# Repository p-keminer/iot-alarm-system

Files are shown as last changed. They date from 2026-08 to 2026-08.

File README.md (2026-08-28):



<div align="center">




</div>

---

<div align="center">
  <a href="#">
   
  </a>
  &nbsp;&nbsp;&nbsp;&nbsp;&nbsp;&nbsp;
  <a href="#">
    
  </a>
  &nbsp;&nbsp;&nbsp;&nbsp;&nbsp;&nbsp;
 <a href="#">
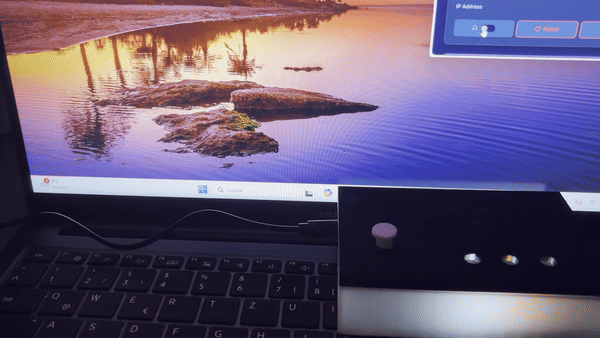
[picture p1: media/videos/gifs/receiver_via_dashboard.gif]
    
  </a>
</div>

---

# IoT-Alarmanlage

Die IoT-Alarmanlage basiert auf einem `Elegoo Uno R3`, zwei `ESP8266` und einem `Raspberry Pi Zero 2 W`. RFID und zwei Reed-Sensoren steuern die lokale Alarm-FSM. Ein Funkpfad uebertraegt Alarmzustaende an den Empfaenger; das Dashboard zeigt Telemetrie, Logs und Aufnahmen und sendet freigegebene Befehle.

Dieses Projekt entstand in meinem ersten Studiensemester und war mein erstes Lernprojekt.

```text
RFID + 2x Reed -> Uno-FSM -> UART -> ESP-Sender -> HMAC-UDP -> ESP-Empfaenger
                         |
                         +-> USB-Serial <-> Alarm-Monitor <-> lokale IPC <-> Dashboard

ESP-Sender + ESP-Empfaenger <-> HTTP/JSON im isolierten IoT-WLAN <-> Raspberry Pi / PHP-API
```

## Aktueller Stand

| Ziel | Aktiver Sketch |
|---|---|
| Uno R3 | `firmware/elegoo_uno_r3/sketchR3/alarm_system/alarm_system.ino` |
| ESP-Sender | `firmware/esp8266/sender/sender.ino` |
| ESP-Empfaenger | `firmware/esp8266/receiver/receiver.ino` |

- Der Uno akzeptiert ohne private `uid_whitelist.local.h` keine Karte. Scharf-/Alarmzustand liegt CRC-geschuetzt in zwei EEPROM-Slots; ein offener Reed-Kreis loest scharf Alarm aus.
- UDP nutzt HMAC-SHA256, strikt monotone persistente Sequenzen und signierte ACKs. HTTP-Zustellungen nutzen getrennte Geraete-Token/-HMACs und ein durables `ALARMv2`-Apply-Journal.
- `nginx`/`PHP-FPM` bedienen den Browser per HTTPS und die ESPs ueber einen auf das IoT-WLAN beschraenkten HTTP-Endpunkt. Der Dienst `iot-alarm-monitor` besitzt exklusiv Serial, Recorder und deren Loeschpfade.
- Der Prototyp besitzt keine formale Produkt-, Safety- oder Security-Freigabe.

## Repository

| Pfad | Inhalt |
|---|---|
| `firmware/` | drei aktive Arduino-Ziele |
| `web/` | Dashboard, API, Monitor und Deploy-Vorlagen |
| `hardware/` | KiCad-, Gerber- und Aufbauquellen |
| `mechanics/` | STL-Dateien und Vorschauen |
| `media/` | Projektfotos und fuenf Demo-GIFs |
| `docs/`, `tests/` | kanonische Dokumentation und Nachweise |

## Einstieg

[Build](docs/BUILD.md#deutsch) · [Hardware](docs/HARDWARE.md#deutsch) · [Web-Dashboard](web/README.md#deutsch) · [Tests](docs/TESTING.md#deutsch) · [Safety](SAFETY.md#deutsch) · [Security](SECURITY.md#deutsch)

## Sicherheitsgrenze

Das System ist ein nicht zertifizierter Lernprototyp. Ausfaelle von Strom, Funk, Speicher, Kamera oder Hardware koennen seine Funktion beeintraechtigen.

## Lokale Konfiguration

RFID-UIDs, WLAN-Daten, Token, HMAC-Secrets, Passwoerter, PINs und Laufzeitdaten bleiben lokal. Vorlagen enden auf `.example`; private Werte liegen in ignorierten `*.local.*`-Dateien oder im geschuetzten `web/data/`.

## Lizenz

Projekt-eigene Inhalte stehen unter der [MIT-Lizenz](LICENSE.md); Drittmaterial behaelt seine jeweiligen Rechte.

<div align="center">



</div>

---

# IoT Alarm System

The IoT alarm system uses an `Elegoo Uno R3`, two `ESP8266` nodes, and a `Raspberry Pi Zero 2 W`. RFID and two reed sensors drive the local alarm FSM. A radio link sends alarm states to the receiver; the dashboard displays telemetry, logs, and recordings and sends approved commands.

This project began during the first semester of my degree and was my first learning project.

```text
RFID + 2x reed -> Uno FSM -> UART -> ESP sender -> HMAC UDP -> ESP receiver
                           |
                           +-> USB serial <-> alarm monitor <-> local IPC <-> dashboard

ESP sender + ESP receiver <-> HTTP/JSON on the isolated IoT WiFi <-> Raspberry Pi / PHP API
```

## Current Status

| Target | Active sketch |
|---|---|
| Uno R3 | `firmware/elegoo_uno_r3/sketchR3/alarm_system/alarm_system.ino` |
| ESP sender | `firmware/esp8266/sender/sender.ino` |
| ESP receiver | `firmware/esp8266/receiver/receiver.ino` |

- Without private `uid_whitelist.local.h`, the Uno accepts no card. Armed/alarm state is CRC-protected across two EEPROM slots; either open reed circuit triggers an armed system.
- UDP uses HMAC-SHA256, strict monotonic persistent sequences, and signed ACKs. HTTP delivery uses separate device tokens/HMACs and a durable `ALARMv2` apply journal.
- `nginx`/`PHP-FPM` serve the browser over HTTPS and the ESPs through an HTTP endpoint restricted to the IoT WiFi. The `iot-alarm-monitor` service exclusively owns serial, the recorder, and their deletion paths.
- The prototype has no formal product, safety, or security approval.

## Repository

| Path | Contents |
|---|---|
| `firmware/` | three active Arduino targets |
| `web/` | dashboard, API, monitor, and deployment templates |
| `hardware/` | KiCad, Gerber, and assembly sources |
| `mechanics/` | STL files and previews |
| `media/` | project photos and five demo GIFs |
| `docs/`, `tests/` | canonical documentation and evidence |

## Getting Started

[Build](docs/BUILD.md#english) · [Hardware](docs/HARDWARE.md#english) · [Web dashboard](web/README.md#english) · [Tests](docs/TESTING.md#english) · [Safety](SAFETY.md#english) · [Security](SECURITY.md#english)

## Security Boundary

The system is an uncertified learning prototype. Power, radio, storage, camera, or hardware failures may impair its operation.

## Local Configuration

RFID UIDs, WiFi credentials, tokens, HMAC secrets, passwords, PINs, and runtime data remain local. Templates end in `.example`; private values live in ignored `*.local.*` files or protected `web/data/`.

## License

Project-owned content uses the [MIT License](LICENSE.md); third-party material retains its respective rights.

<div align="center">



</div>

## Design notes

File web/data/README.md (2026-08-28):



<div align="center">




</div>

---

# Laufzeitdaten

Dieses Verzeichnis enthaelt den lokalen Zustand einer Installation. Ausser dieser README wird nichts daraus eingecheckt.

| Pfad | Inhalt |
|---|---|
| `settings.json` | Hashes, getrennte Geraete-Token/-HMACs, UDP-Secret und Einstellungen |
| `settings.bootstrap.lock` | Prozess-Lock fuer Bootstrap und Secret-Rotation |
| `.bootstrap-credentials` | Bootstrap-Fallback, nur wenn kein externer Pfad gesetzt ist |
| `status.json` | letzter ESP-/Kamerastatus, nicht der Uno-Zustand |
| `commands.json`, `update_*.json` | offene Node-Kommandos und -Konfigurationen |
| `delivery_state.json`, `delivery_queue.lock` | monotone Zaehler und Zustell-Lock |
| `alarm_monitor.json` | alleinige Dashboard-Quelle fuer Uno, Serial und Aufnahme |
| `telemetry.csv` | Telemetrie-Zeitreihe |
| `log.txt`, `log.txt.1`, `log.txt.2` | groessenbegrenzt rotierter Alarm-Monitor-Log |
| `api.log`, `user_logs.json` | begrenzter API-/Geraete-Log und Administrator-Auditlog |
| `login_attempts.json` | Login-Brute-Force-Tracking |
| `alarm_pin_attempts.json` | getrenntes Alarm-PIN-Lockout-Ledger |
| `ratelimit/` | API-Ratenzaehler pro Quell-IP |
| `recordings/` | lokale Kameraaufnahmen |

Im kanonischen Deployment zeigt `IOT_ALARM_BOOTSTRAP_FILE` vor dem ersten Aufruf auf eine `0600`-Datei ausserhalb des Webroots. Ohne diesen Wert verwendet die Anwendung `.bootstrap-credentials` in diesem von nginx gesperrten Verzeichnis. Nach Passwort-/PIN-Wechsel und ESP-Provisionierung sicher loeschen.

Das Datenverzeichnis ist setgid `2770`, `recordings/` ist `0750`, regulaere Runtime-Dateien sind `0640` und der Bootstrap-Fallback ist `0600`. Der Daemon besitzt den Serial-/Recorderpfad; sein Socket liegt separat unter `/run/iot-alarm-monitor/control.sock` als `0660` fuer die Gruppe `www-data`. Vollstaendige Einrichtung: [Build](../../docs/BUILD.md#de-web-deployment).

Die Daten koennen Secrets, IP-Adressen, Zeitstempel und Aufnahmen enthalten. Backups gleich streng schuetzen, nicht oeffentlich weitergeben und nach der Aufbewahrungsfrist loeschen. Siehe [Security](../../SECURITY.md#deutsch).

<div align="center">



</div>

---

# Runtime Data

This directory contains the local state of an installation. Nothing except this README is committed.

| Path | Contents |
|---|---|
| `settings.json` | hashes, separate device tokens/HMACs, UDP secret, and settings |
| `settings.bootstrap.lock` | process lock for bootstrap and secret rotation |
| `.bootstrap-credentials` | bootstrap fallback only when no external path is set |
| `status.json` | latest ESP/camera status, not Uno state |
| `commands.json`, `update_*.json` | pending node commands and configurations |
| `delivery_state.json`, `delivery_queue.lock` | monotonic counters and delivery lock |
| `alarm_monitor.json` | sole dashboard source for Uno, serial, and recording state |
| `telemetry.csv` | telemetry time series |
| `log.txt`, `log.txt.1`, `log.txt.2` | size-bounded rotating alarm-monitor log |
| `api.log`, `user_logs.json` | bounded API/device log and administrator audit log |
| `login_attempts.json` | login brute-force tracking |
| `alarm_pin_attempts.json` | separate alarm-PIN lockout ledger |
| `ratelimit/` | API rate counters by source IP |
| `recordings/` | local camera recordings |

In the canonical deployment, `IOT_ALARM_BOOTSTRAP_FILE` points to a `0600` file outside the web root before the first request. Without that value, the application uses `.bootstrap-credentials` in this nginx-blocked directory. Delete it securely after password/PIN changes and ESP provisioning.

The data directory is setgid `2770`, `recordings/` is `0750`, regular runtime files are `0640`, and the bootstrap fallback is `0600`. The daemon owns serial and recording resources; its separate socket is `/run/iot-alarm-monitor/control.sock`, mode `0660`, for group `www-data`. See [Build](../../docs/BUILD.md#en-web-deployment) for complete setup.

The data may contain secrets, IP addresses, timestamps, and recordings. Protect backups equally, do not share them publicly, and delete them after their retention period. See [Security](../../SECURITY.md#english).

<div align="center">



</div>

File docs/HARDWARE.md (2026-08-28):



<div align="center">




</div>

---

# Hardware

Die Pinbelegung ist aus den drei aktiven Sketchen abgeleitet. Schaltbilder und KiCad-Dateien bleiben die Referenz fuer den realen Aufbau; vor dem Einschalten immer gegen die vorhandene Platine pruefen.

## Komponenten

| Anzahl | Komponente | Aufgabe |
|---:|---|---|
| 1 | Elegoo Uno R3 / ATmega328P | lokale Alarm-FSM, RFID und Reed-Sensoren |
| 2 | NodeMCU V2 / ESP8266 | Funk-Sender und entfernter Empfaenger |
| 1 | Raspberry Pi Zero 2 W | Dashboard, API, Serial-Monitor, optionale Kamera |
| 1 + 2 | MFRC522 + KY-021 / Reed-Modul | RFID-Zugang und Tuer-/Fensterkontakte |
| 3 + 7 | aktive Summer + LEDs | akustischer Alarm und Statusanzeigen |
| 1 | Raspberry-Pi-Kameramodul | optionale Alarmaufnahme |

Erforderlich sind ausserdem passende LED-Vorwiderstaende, ein Pegelwandler oder berechneter Spannungsteiler fuer Uno TX, Taster, Steckverbinder und eine stabile Versorgung.

## Pinbelegung

### Uno R3

| Pin | Funktion | Hinweis |
|---|---|---|
| `D0/RX` | Befehle ueber USB-Serial | gemeinsame Hardware-UART |
| `D1/TX` | Events an ESP-Sender und USB-Serial | `5 V`; zum ESP pegeln |
| `D2`, `D3` | Reed-Sensor 1 und 2 | `INPUT_PULLUP`; `HIGH` = offen |
| `D5` | lokaler Summer | Ausgang |
| `D6`, `D7`, `D8` | Alarm-/Scharf-LED, Sensor-LED 1 und 2 | Ausgang |
| `D9` | MFRC522 `RST` | `3.3 V`-Peripherie |
| `D10` | MFRC522 `SS/SDA` | SPI Chip Select |
| `D11`, `D12`, `D13` | MFRC522 `MOSI`, `MISO`, `SCK` | `D13` teilt die Board-LED |

Bereits ein offener Reed-Kreis loest im scharfen Zustand aus. Scharf- und Alarmzustand liegen mit Sequenz, CRC und Commit-Markierung in zwei EEPROM-Slots; ein beschaedigter nichtleerer Stand startet fail-secure im Alarm. Ohne lokale UID-Datei akzeptiert der Uno keine RFID-Karte.

### ESP8266-Sender

| NodeMCU-Pin | GPIO | Funktion |
|---|---:|---|
| `RX` | `GPIO3` | `ALARM_ON`/`ALARM_OFF` vom Uno, `9600` Baud |
| `D3` | `GPIO0` | Factory-Reset-Taster, `INPUT_PULLUP` |
| `D5` | `GPIO14` | WLAN-LED |
| `LED_BUILTIN` | `GPIO2` | Alarm-/Sende-LED, aktiv-low |

Der Factory Reset wird erst nach mehr als zehn Sekunden Tastendruck beim Loslassen ausgeloest. `GPIO0` und `GPIO2` beeinflussen den Bootmodus; externe Schaltungen muessen die erforderlichen Einschaltpegel erhalten.

### ESP8266-Empfaenger

| NodeMCU-Pin | GPIO | Funktion |
|---|---:|---|
| `D1`, `D2` | `GPIO5`, `GPIO4` | rote und gelbe Alarm-LED |
| `D3` | `GPIO0` | WLAN-LED |
| `D5`, `D6` | `GPIO14`, `GPIO12` | Summer 1 und 2 |
| `D7` | `GPIO13` | Toggle-/Factory-Reset-Taster, `INPUT_PULLUP` |

Ein Druck unter einer Sekunde schaltet den entfernten Alarm um. Mehr als zehn Sekunden loesen beim Loslassen den Factory Reset aus; dazwischen erfolgt keine Aktion.

## Versorgung und Pegel

- Alle verbundenen Baugruppen brauchen eine gemeinsame Masse.
- ESP8266-GPIOs und MFRC522 arbeiten mit `3.3 V`; Uno TX zum ESP pegeln.
- Eine stabile Versorgung und Abblockung muessen WLAN-Stromspitzen tragen.
- Fuer einen per USB versorgten Uno ist der Sender mit externer ESP-Versorgung die empfohlene Variante.
- Stromhungrige Summer oder mehrere LEDs bei Bedarf ueber Treiber schalten.
- Es gibt keine galvanische Trennung. Vor Umverdrahtung Strom und USB trennen.

## Leiterplatten und Mechanik

| Pfad | Inhalt | Fertigungsdaten |
|---|---|---|
| `hardware/pcb/receiver/` | Empfaenger-KiCad-Projekt und Renderings | `receiver_gerber.zip` |
| `hardware/pcb/sender/` | Sender-Basisprojekt und Renderings | `sender_r3_gerber.zip` |
| `hardware/pcb/sender/sender_r3_external.*` | Sender mit externer ESP-Versorgung | `sender_r3_external_gerber/` |

Die ZIPs sind fuer Basis-Sender und Empfaenger kanonisch; fuer die externe Variante ist der lose Gerber-Satz die einzige Fertigungsquelle. Vor Bestellung Lagen, Bohrungen, Kontur, Leiterbahnbreiten, Polaritaeten und Abmessungen im Gerber-Viewer pruefen. Die Dateien sind keine Produktionsfreigabe.

| STL-Verzeichnis | Modell |
|---|---|
| `mechanics/prints_3d/sender/` | Sendergehaeuse R3 |
| `mechanics/prints_3d/receiver/` | Empfaengergehaeuse |
| `mechanics/prints_3d/reed_sensor/` | Reed-Sensorgehaeuse |
| `mechanics/prints_3d/rfid_sensor/` | RFID-Lesergehaeuse |

Jeder Ordner enthaelt eine STL-Datei und eine Vorschau. Toleranzen, Schraubpunkte und Ausschnitte vor dem Druck an der realen Hardware pruefen.

## Aufbau

1. Versorgung und Pegel ohne Controller messen; dann Uno, RFID und beide Reed-Kreise einzeln testen.
2. Sender und Empfaenger getrennt flashen und lokal provisionieren.
3. UART nur mit gemeinsamer Masse und korrektem Pegel verbinden.
4. Funkpfad zuerst ohne laute Aktoren pruefen; Pi, API und Kamera zuletzt anbinden.

Aufbaufotos liegen unter `media/photos/`, Schalt- und Lochrasterzeichnungen unter `hardware/schematics/`.

<div align="center">



</div>

---

# Hardware

The pin map is derived from the three active sketches. Schematics and KiCad files remain the reference for the physical build; always compare them with the actual board before applying power.

## Components

| Qty | Component | Purpose |
|---:|---|---|
| 1 | Elegoo Uno R3 / ATmega328P | local alarm FSM, RFID, and reed sensors |
| 2 | NodeMCU V2 / ESP8266 | radio sender and remote receiver |
| 1 | Raspberry Pi Zero 2 W | dashboard, API, serial monitor, optional camera |
| 1 + 2 | MFRC522 + KY-021 / reed module | RFID access and door/window contacts |
| 3 + 7 | active buzzers + LEDs | audible alarm and status indicators |
| 1 | Raspberry Pi camera module | optional alarm recording |

The build also needs suitable LED resistors, a level shifter or calculated divider for Uno TX, buttons, connectors, and a stable power supply.

## Pin Map

### Uno R3

| Pin | Function | Note |
|---|---|---|
| `D0/RX` | commands over USB serial | shared hardware UART |
| `D1/TX` | events to ESP sender and USB serial | `5 V`; shift for ESP |
| `D2`, `D3` | reed sensors 1 and 2 | `INPUT_PULLUP`; `HIGH` = open |
| `D5` | local buzzer | output |
| `D6`, `D7`, `D8` | alarm/armed LED, sensor LEDs 1 and 2 | output |
| `D9` | MFRC522 `RST` | `3.3 V` peripheral |
| `D10` | MFRC522 `SS/SDA` | SPI chip select |
| `D11`, `D12`, `D13` | MFRC522 `MOSI`, `MISO`, `SCK` | `D13` shares the board LED |

Either open reed circuit triggers an armed system. Armed and alarm state use sequence, CRC, and commit markers across two EEPROM slots; corrupt non-empty state boots fail-secure into alarm. Without a local UID file, the Uno accepts no RFID card.

### ESP8266 Sender

| NodeMCU pin | GPIO | Function |
|---|---:|---|
| `RX` | `GPIO3` | `ALARM_ON`/`ALARM_OFF` from Uno at `9600` baud |
| `D3` | `GPIO0` | factory-reset button, `INPUT_PULLUP` |
| `D5` | `GPIO14` | WiFi LED |
| `LED_BUILTIN` | `GPIO2` | alarm/transmit LED, active-low |

Factory reset occurs on release after holding the button for more than ten seconds. `GPIO0` and `GPIO2` affect boot mode; external circuitry must preserve the required levels during power-up.

### ESP8266 Receiver

| NodeMCU pin | GPIO | Function |
|---|---:|---|
| `D1`, `D2` | `GPIO5`, `GPIO4` | red and yellow alarm LEDs |
| `D3` | `GPIO0` | WiFi LED |
| `D5`, `D6` | `GPIO14`, `GPIO12` | buzzers 1 and 2 |
| `D7` | `GPIO13` | toggle/factory-reset button, `INPUT_PULLUP` |

A press below one second toggles the remote alarm. More than ten seconds triggers factory reset on release; the interval between them has no action.

## Power and Logic Levels

- Every connected board needs a common ground.
- ESP8266 GPIO and the MFRC522 use `3.3 V`; level-shift Uno TX to the ESP.
- A stable, decoupled supply must support WiFi current peaks.
- For a USB-powered Uno, the sender with an external ESP supply is recommended.
- Drive high-current buzzers or multiple LEDs through suitable drivers.
- There is no galvanic isolation. Disconnect power and USB before rewiring.

## PCBs and Mechanics

| Path | Contents | Manufacturing data |
|---|---|---|
| `hardware/pcb/receiver/` | receiver KiCad project and renderings | `receiver_gerber.zip` |
| `hardware/pcb/sender/` | base sender project and renderings | `sender_r3_gerber.zip` |
| `hardware/pcb/sender/sender_r3_external.*` | sender with external ESP supply | `sender_r3_external_gerber/` |

The ZIPs are canonical for the base sender and receiver; the loose Gerbers are the only manufacturing source for the external variant. Before ordering, verify layers, drills, outline, trace widths, polarities, and dimensions in a Gerber viewer. These files are not a production release.

| STL directory | Model |
|---|---|
| `mechanics/prints_3d/sender/` | R3 sender enclosure |
| `mechanics/prints_3d/receiver/` | receiver enclosure |
| `mechanics/prints_3d/reed_sensor/` | reed-sensor enclosure |
| `mechanics/prints_3d/rfid_sensor/` | RFID-reader enclosure |

Each directory contains one STL and one preview. Check tolerances, mounting points, and cut-outs against the real hardware before printing.

## Assembly

1. Measure power and logic levels without controllers; then test the Uno, RFID reader, and both reed circuits.
2. Flash and locally provision sender and receiver separately.
3. Connect UART only with common ground and the correct logic level.
4. Test the radio path without loud actuators; integrate Pi, API, and camera last.

Assembly photos are under `media/photos/`; circuit and perfboard drawings are under `hardware/schematics/`.

<div align="center">



</div>

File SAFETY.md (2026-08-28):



<div align="center">




</div>

---

# Safety

Dieses Repository beschreibt einen nicht zertifizierten Lern- und Demonstrationsprototyp.

## Grenzen

- Das System ist keine zertifizierte Alarmanlage.
- Strom-, WLAN-, Software-, Sensor-, Speicher- und Verdrahtungsfehler koennen LEDs, Summer, Webstatus und Kamera ausfallen lassen.
- Ein offener Reed-Kreis loest scharf Alarm aus. Das behandelt Kabelbruch konservativ, ist aber keine zertifizierte Sabotageerkennung.
- Der Uno stellt Scharf-/Alarmzustand aus EEPROM wieder her; ein Neustart schaltet nicht unscharf.
- Bei unlesbarem Sicherheitszustand aktiviert der Empfaenger fail-secure seine Aktoren. Der lokale Uno-Pfad bleibt auch bei Ausfall von Funk oder Dashboard massgeblich.

## Kamera und Datenschutz

Nur eigene oder ausdruecklich freigegebene Bereiche aufnehmen. Aufnahmen und Logs koennen Personen, Zeitstempel, IP-Adressen und Anwesenheitsmuster enthalten; lokale Gesetze, Informationspflichten, Zugriffsschutz, verschluesselte Backups und Aufbewahrungsfristen beachten.

Netzwerk- und Zugriffsgrenzen: [Security](SECURITY.md#deutsch).

<div align="center">



</div>

---

# Safety

This repository documents an uncertified learning and demonstration prototype.

## Limitations

- The system is not a certified alarm system.
- Power, WiFi, software, sensor, storage, and wiring faults can disable LEDs, buzzers, web status, or the camera.
- Either open reed circuit triggers an armed system. This treats a broken wire conservatively but is not certified tamper detection.
- The Uno restores armed/alarm state from EEPROM; a restart does not disarm it.
- Unreadable security state makes the receiver fail-secure drive its actuators. The local Uno path remains authoritative if radio or dashboard access fails.

## Camera and Privacy

Record only your own areas or areas with explicit permission. Recordings and logs may contain people, timestamps, IP addresses, and presence patterns; observe local law, notification duties, access control, encrypted backups, and retention periods.

Network and access boundaries: [Security](SECURITY.md#english).

<div align="center">



</div>

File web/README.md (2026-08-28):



<div align="center">




</div>

---

# Web-Dashboard

Die leichtgewichtige PHP-Anwendung fuer den Raspberry Pi Zero 2 W verwendet JSON-/CSV-Dateien statt einer Datenbank. Sie verbindet ESP-Telemetrie und -Kommandos, den Uno ueber einen dedizierten Serial-Dienst sowie optionale Kamera-Streams und Alarmaufnahmen.

## Ansichten

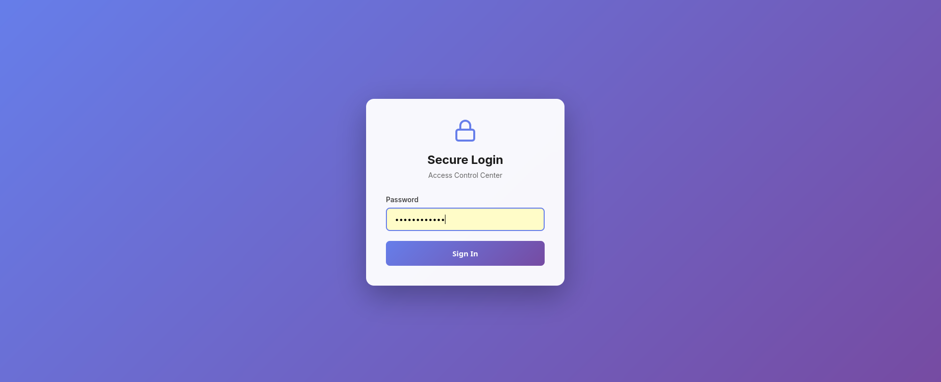
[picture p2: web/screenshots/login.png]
Login

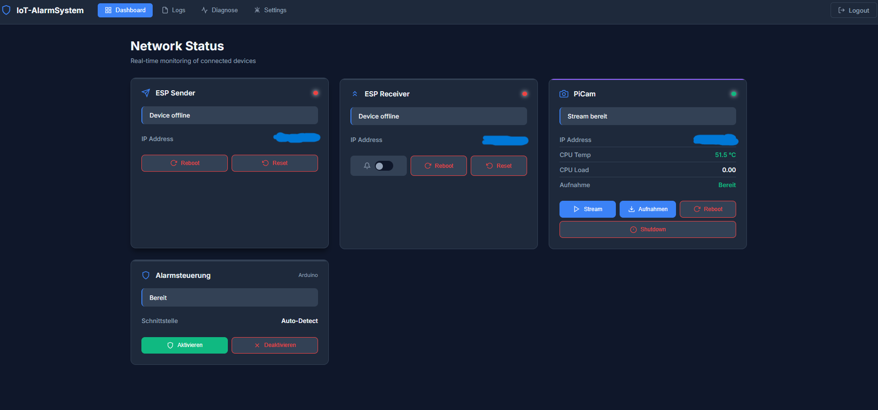
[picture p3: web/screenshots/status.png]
Status

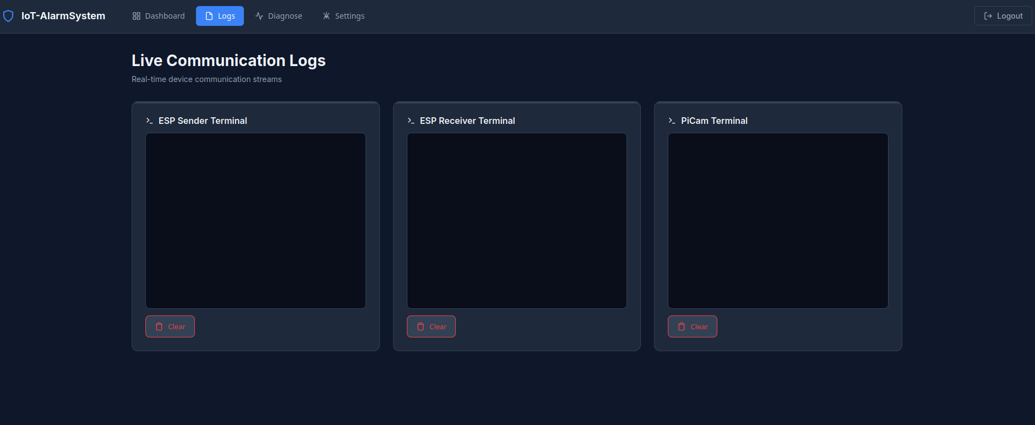
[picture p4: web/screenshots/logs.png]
Logs

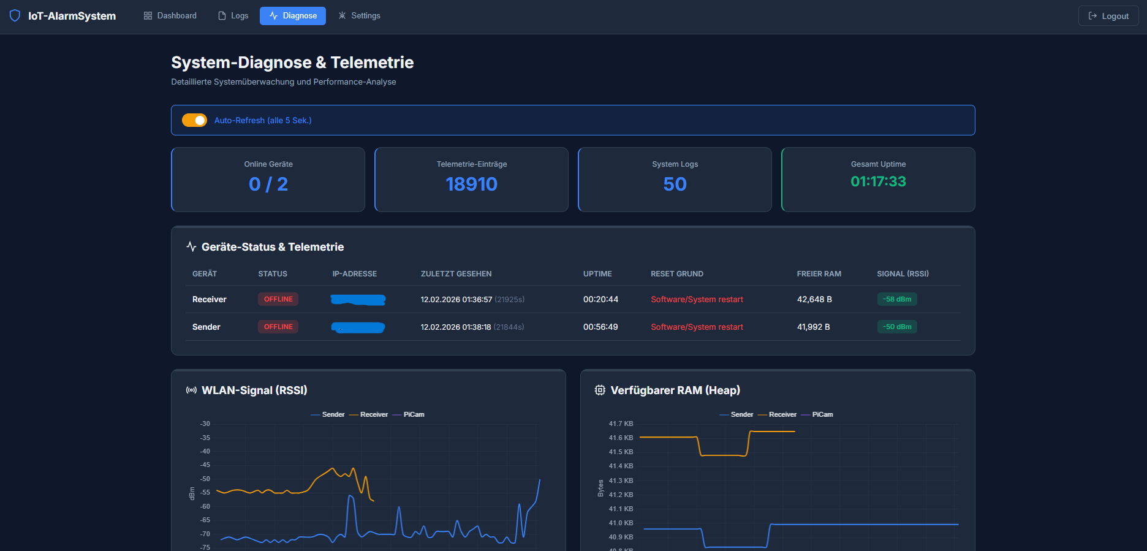
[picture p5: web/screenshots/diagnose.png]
Diagnose

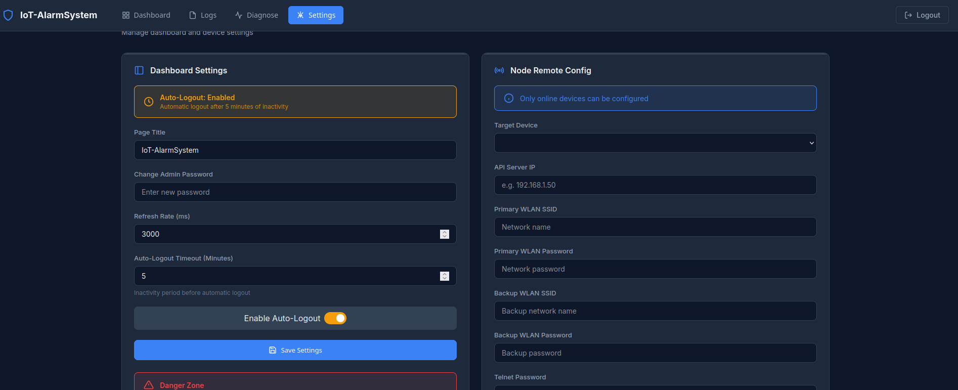
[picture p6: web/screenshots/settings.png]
Einstellungen

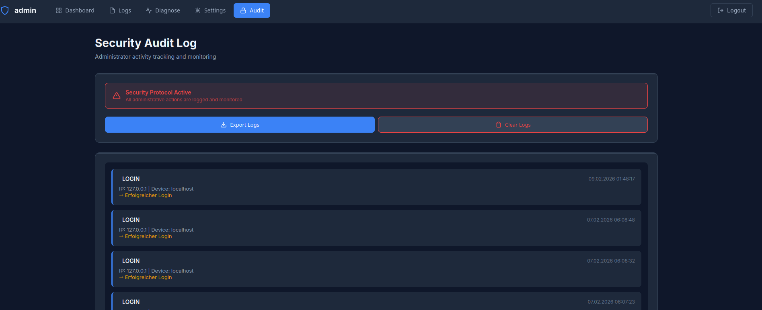
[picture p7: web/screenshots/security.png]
Audit


## Architektur

| Pfad | Aufgabe |
|---|---|
| `index.php`, `login.php` | geschuetzte Oberflaeche und Login |
| `api.php` | Dashboard-Aktionen und ESP-Endpunkt |
| `stream.php` | authentifizierte Kameraansicht |
| `includes/` | Konfiguration, Authentifizierung und Datenzugriff |
| `views/`, `css/`, `js/` | statische Oberflaeche |
| `alarm_monitor.py` | alleiniger Serial-, Recorder- und Loeschprozess |
| `alarm_monitor.service` | gehaertete systemd-Unit |
| `deploy/` | nginx-, Fail2ban- und systemd-Vorlagen |
| `data/` | ignorierter lokaler Laufzeitzustand |

Browserzugriff erreicht nginx ausschliesslich ueber HTTPS; Port 80 leitet auf den festen HTTPS-Namen um. Ein separater HTTP-Listener bindet die IP-Adresse des Pi im IoT-WLAN, erlaubt nur dessen isoliertes Subnetz und stellt dort ausschliesslich `api.php` bereit. Interne Verzeichnisse und Dateitypen werden nicht statisch ausgeliefert.

PHP oeffnet weder Serial noch ffmpeg. Freigegebene Aktionen gehen ueber den
lokalen Socket `/run/iot-alarm-monitor/control.sock` an den Dienst; nur dieser
Prozess besitzt `dialout`, Recorder und Aufnahme-Loeschpfad.

## Funktionen

- Live-Status, RSSI, Heap, Uptime und Resetgrund beider ESPs
- Kommunikations-, System- und Auditlogs sowie Telemetrie-CSV
- Auditansicht/-export mit fuenf Minuten gueltiger serverseitiger PIN-Freigabe
- PIN-Schutz fuer Alarm, Reboot, Datenreset und Aufnahmeaktionen
- getrennte Node-Kommandos und -Konfigurationen mit Geraete-ACK
- Admin-Passwort, Alarm-PIN, Session-Timeout und Aktualisierungsintervall
- optionale MJPEG-Ansicht sowie automatische und manuelle Aufnahmen

Google Fonts, `unpkg.com` und `jsDelivr` bleiben externe Browserabhaengigkeiten.
Ohne Internet funktionieren die Serverpfade weiter; Icons, Schrift oder Charts
koennen fehlen. Die Grenze ist in [Security](../SECURITY.md#deutsch) bewertet.

## Ersteinrichtung

Eine neue Installation erzeugt Admin-Passwort, Alarm-PIN, getrennte API-/Delivery-Secrets fuer Sender, Empfaenger und Kamera sowie ein eigenes UDP-Secret. Es gibt keine bekannten Standardzugangsdaten.

1. Deployment nach [Build](../docs/BUILD.md#de-web-deployment) installieren.
2. Dashboard ueber HTTPS aufrufen und Bootstrap-Datei lokal lesen.
3. Admin-Passwort und Alarm-PIN ersetzen.
4. Jeden ESP mit seinem eigenen API-/Delivery-Paar und dem gemeinsamen
   UDP-Secret provisionieren.
5. Bootstrap-Datei sicher loeschen.

## Alarm-Monitor und Betrieb

Der Dienst akzeptiert Serial nur nach einem gueltigen `STATUS`-Handshake,
gleicht den Zustand periodisch ab und bestaetigt Scharf-/Unscharf-Befehle erst
nach passendem Snapshot. Bei Verbindungsverlust bleibt ein Alarm konservativ
erhalten. Aufnahmen besitzen Zeit-, Groessen- und Speichergrenzen, begrenzte
Start-Retries und Schutz vor dem Loeschen der aktiven Datei. `log.txt` rotiert;
PHP schreibt getrennt nach `api.log`. Die aktuellen Grenzwerte stehen in der
[Dienstvorlage](deploy/systemd/iot-alarm-monitor.env.example).

```bash
sudo nginx -t
sudo systemctl status nginx php8.4-fpm iot-alarm-monitor.service
sudo journalctl -u iot-alarm-monitor.service -f
sudo ls -l /run/iot-alarm-monitor/control.sock
sudo fail2ban-client status iot-login
```

Runtime-Dateien nie committen oder oeffentlich weitergeben; ihr Manifest
steht in [data/README.md](data/README.md#deutsch). Der ESP-HTTP-Endpunkt darf
nicht aus WAN, Gast-, Campus- oder anderen unkontrollierten Netzen erreichbar
sein.

<div align="center">



</div>

---

# Web Dashboard

This lightweight PHP application for the Raspberry Pi Zero 2 W uses JSON/CSV files instead of a database. It combines ESP telemetry and commands, Uno control through a dedicated serial service, and optional camera streams and alarm recordings.

## Views

Login
Status
Logs
Diagnostics
Settings
Audit

## Architecture

| Path | Purpose |
|---|---|
| `index.php`, `login.php` | protected interface and login |
| `api.php` | dashboard actions and ESP endpoint |
| `stream.php` | authenticated camera view |
| `includes/` | configuration, authentication, and data access |
| `views/`, `css/`, `js/` | static interface |
| `alarm_monitor.py` | sole serial, recorder, and deletion process |
| `alarm_monitor.service` | hardened systemd unit |
| `deploy/` | nginx, Fail2ban, and systemd templates |
| `data/` | ignored local runtime state |

Browser access reaches nginx only over HTTPS; port 80 redirects to the fixed HTTPS name. A separate HTTP listener binds the Pi address on the IoT WiFi, permits only that isolated subnet, and exposes only `api.php`. Internal directories and file types are never served statically.

PHP opens neither serial nor ffmpeg. Approved actions reach the service over
the local `/run/iot-alarm-monitor/control.sock` socket; only that process owns
`dialout`, the recorder, and recording deletion.

## Features

- live status, RSSI, heap, uptime, and reset reason for both ESPs
- communication, system, and audit logs plus telemetry CSV
- audit view/export with a five-minute server-side PIN grant
- PIN protection for alarm, reboot, data reset, and recording actions
- separate node commands and configurations with device ACKs
- admin password, alarm PIN, session timeout, and refresh interval
- optional MJPEG view plus automatic and manual recordings

Google Fonts, `unpkg.com`, and `jsDelivr` remain external browser dependencies.
Server paths keep working offline, but icons, fonts, or charts may be missing.
This boundary is assessed in [Security](../SECURITY.md#english).

## First-Time Setup

A new installation creates an admin password, alarm PIN, separate API/delivery
secrets for sender, receiver, and camera, plus a separate UDP secret. There are
no known default credentials.

1. Install the deployment from [Build](../docs/BUILD.md#en-web-deployment).
2. Open the dashboard over HTTPS and read the bootstrap file locally.
3. Replace the admin password and alarm PIN.
4. Provision each ESP with its own API/delivery pair and the shared UDP secret.
5. Securely delete the bootstrap file.

## Alarm Monitor and Operation

The service accepts serial only after a valid `STATUS` handshake, periodically
reconciles state, and confirms arm/disarm only after a matching snapshot. It
conservatively retains an alarm on connection loss. Recordings have time,
size, and free-space limits, bounded start retries, and active-file deletion
protection. `log.txt` rotates; PHP writes separately to `api.log`. Current
limits live in the [service template](deploy/systemd/iot-alarm-monitor.env.example).

```bash
sudo nginx -t
sudo systemctl status nginx php8.4-fpm iot-alarm-monitor.service
sudo journalctl -u iot-alarm-monitor.service -f
sudo ls -l /run/iot-alarm-monitor/control.sock
sudo fail2ban-client status iot-login
```

Never commit or publicly share runtime files; see their manifest
in [data/README.md](data/README.md#english). The ESP HTTP endpoint must not be
reachable from WAN, guest, campus, or other untrusted networks.

<div align="center">



</div>

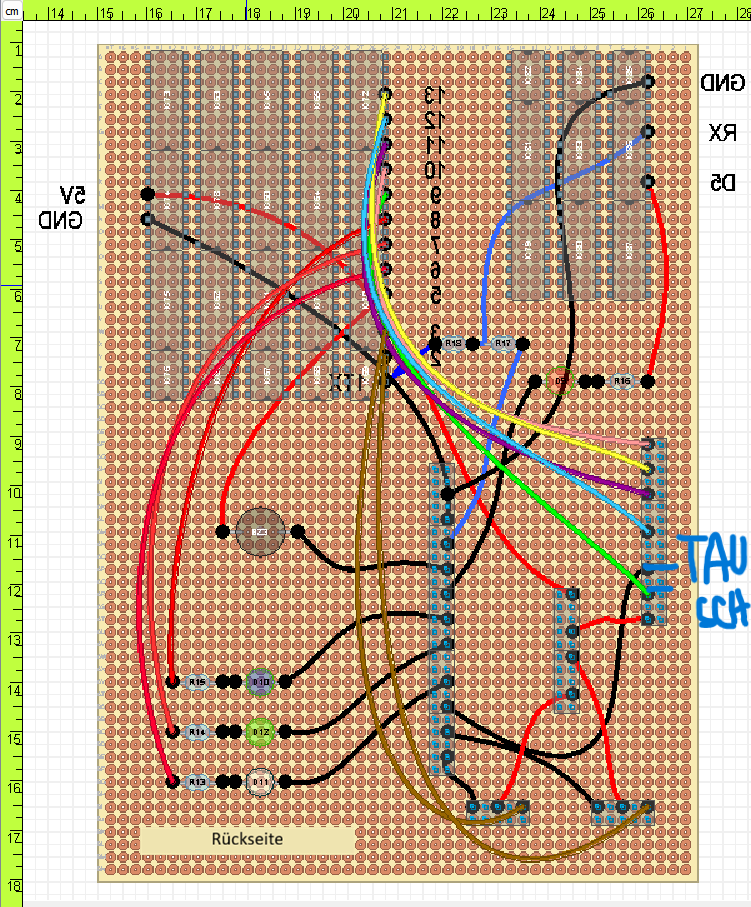
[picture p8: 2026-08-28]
hardware/schematics/perfboard/sender/sender_perfboard_back.png

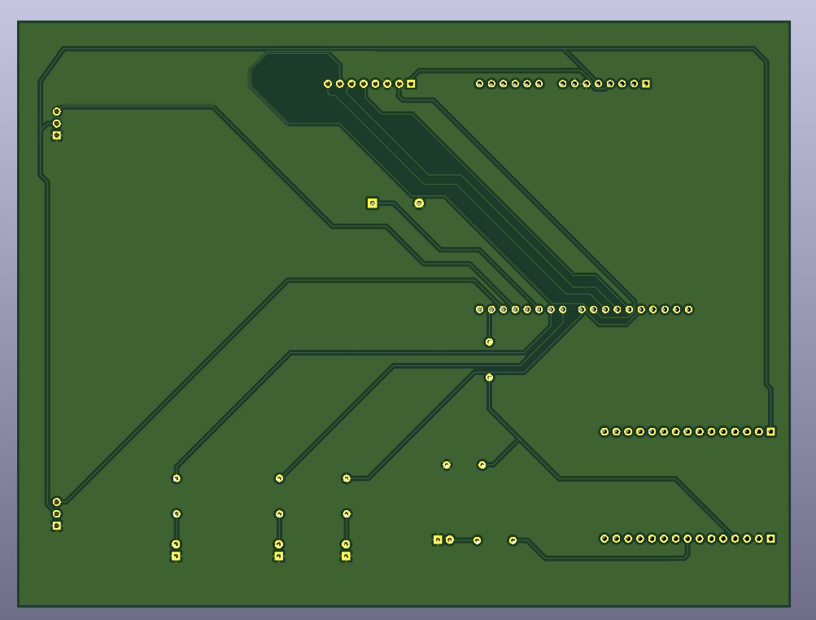
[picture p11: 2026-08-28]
hardware/pcb/sender/pcb_sender_r3_back.png

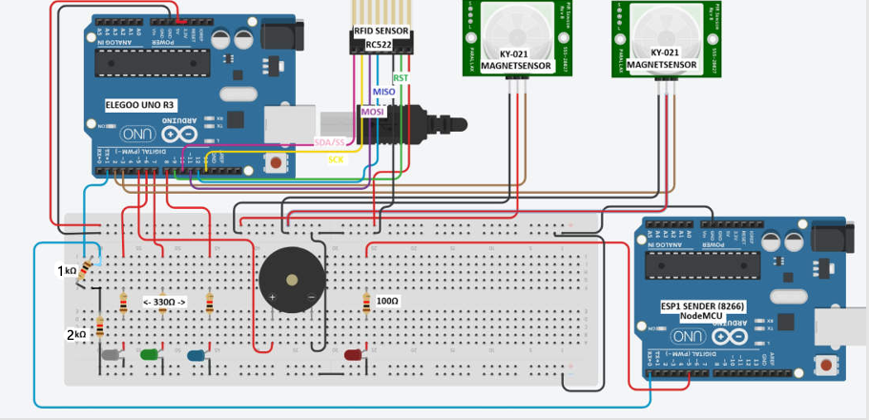
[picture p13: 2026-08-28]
hardware/schematics/circuit_diagram/sender_esp_circuit_r3.png

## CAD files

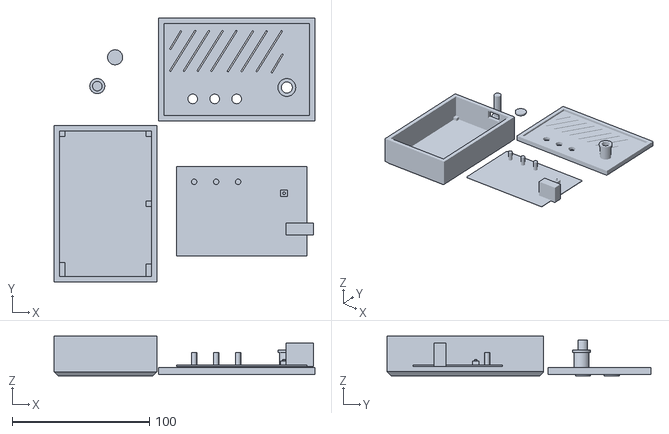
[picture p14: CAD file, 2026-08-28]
mechanics/prints_3d/receiver/receiver_housing.stl
190.0 x 192.0 x 29.0

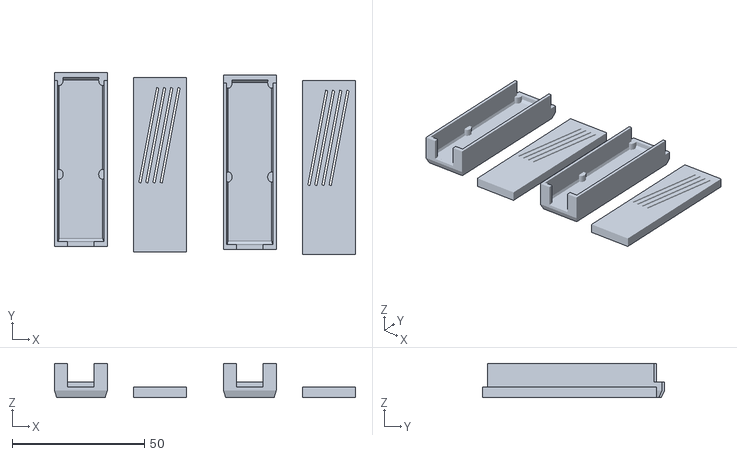
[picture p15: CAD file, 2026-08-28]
mechanics/prints_3d/reed_sensor/reed_sensor_gehaeuse.stl
114.0 x 69.0 x 13.0

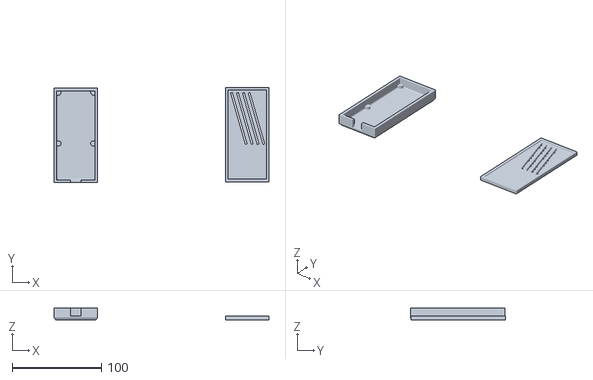
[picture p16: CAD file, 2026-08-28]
mechanics/prints_3d/rfid_sensor/rfid_sensor_gehaeuse.stl
241.0 x 107.0 x 13.0

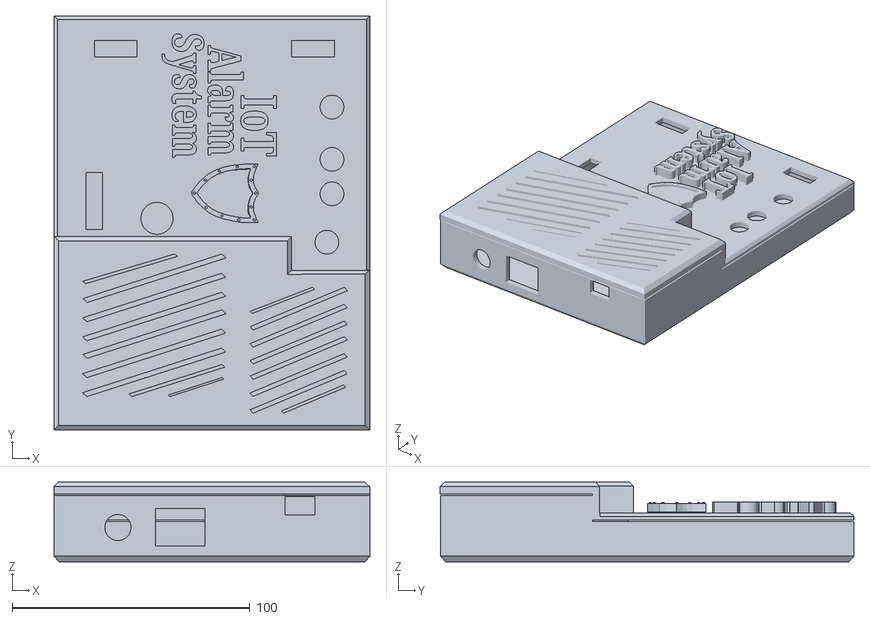
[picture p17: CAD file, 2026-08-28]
mechanics/prints_3d/sender/sender_r3_housing.stl
133.0 x 174.2 x 33.6

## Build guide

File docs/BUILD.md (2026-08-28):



<div align="center">




</div>

---

# Build und Installation

Diese Anleitung gilt fuer die drei aktiven Firmwareziele und das kanonische
Raspberry-Pi-Deployment. Historische Sketche sind kein Build-Input.

## Verifizierte Versionen

Arduino CLI `1.5.1`; ESP8266-Core `3.1.2`; AVR Boards `1.8.8`;
ArduinoJson `7.4.3`; WiFiManager `2.0.17`; TelnetStream `1.3.0`;
NetApiHelpers `1.0.3`; MFRC522 `1.4.12`; PHP `8.4.25`; Node.js `24.14`.

Neuere Versionen sind nicht Teil des Nachweises. Bekannte ArduinoJson-/
ESP8266-Deprecation-Warnungen sind keine Build-Fehler.

## Arduino-Toolchain

```bash
arduino-cli config init
arduino-cli core update-index
arduino-cli core install arduino:avr@1.8.8
arduino-cli core install esp8266:esp8266@3.1.2 --additional-urls https://arduino.esp8266.com/stable/package_esp8266com_index.json
arduino-cli lib install "ArduinoJson@7.4.3"
arduino-cli lib install "WiFiManager@2.0.17"
arduino-cli lib install "TelnetStream@1.3.0"
arduino-cli lib install "NetApiHelpers@1.0.3"
arduino-cli lib install "MFRC522@1.4.12"
```

## Firmware bauen

```bash
arduino-cli compile --fqbn arduino:avr:uno firmware/elegoo_uno_r3/sketchR3/alarm_system
arduino-cli compile --fqbn esp8266:esp8266:nodemcuv2 firmware/esp8266/sender
arduino-cli compile --fqbn esp8266:esp8266:nodemcuv2 firmware/esp8266/receiver
```

Zum Upload `--port <PORT> --upload` anhaengen.

## Lokale RFID-UIDs

Der Uno-Default baut fail-closed und akzeptiert keine Karte. Fuer reale Hardware
`uid_whitelist.local.h.example` nach `uid_whitelist.local.h` kopieren und UID-Bytes
samt Laenge lokal einsetzen. Die ignorierte `*.local.h` nie committen. Die
unveraenderte Vorlage kompiliert absichtlich nicht; unscharf mit eigener Karte testen.

## ESP-Ersteinrichtung

Ohne Haupt-SSID startet `Alarm-Sender-Konfig` bzw. `Alarm-Empfaenger-Konfig`;
zufaellige WPA2-Setup-AP-/Telnet-Passwoerter erscheinen nur seriell. Im isolierten
Netz setzen: dasselbe UDP-HMAC-Secret (`>=32` Zeichen) auf beiden ESPs, je Geraet
einen eigenen 32-stelligen API-Token und Delivery-HMAC (`>=32`), ausserdem API-IP,
Haupt-/Backup-WLAN und Debug-Telnet-Passwort.

Sender- und Empfaengerwerte nie vertauschen. Beide gemeinsam auf `V15`
aktualisieren; signierte UDP-ACKs und `ALARMv2` sind mit Alt-Firmware nicht
voll kompatibel. Bei Migration bleibt ein geeignetes Alt-HMAC nur als
UDP-Secret; globale Alt-Token/-Delivery-Schluessel werden entfernt. Intakte
WLAN-Werte koennen bleiben; fehlende Konfiguration oder Delivery-HMAC erfordert
neue Provisionierung und legt dauerhafte UDP-/API-High-Watermarks an.

## Raspberry-Pi-Deployment

Browserzugriff laeuft per HTTPS ueber `nginx`; nur `api.php` besitzt zusaetzlich
einen auf das IoT-Subnetz beschraenkten HTTP-Listener fuer die ESPs.

### Pakete und Dateien

```bash
sudo apt update
sudo apt install nginx php8.4-fpm python3-serial ffmpeg rsync fail2ban apache2-utils
sudo install -d -o root -g root -m 0755 /var/www/html
sudo rsync -a --delete --chown=root:root --exclude data/ --exclude deploy/ --exclude README.md web/ /var/www/html/
sudo useradd --system --no-create-home --home-dir /nonexistent --shell /usr/sbin/nologin --gid www-data iot-alarm-monitor
sudo install -d -o iot-alarm-monitor -g www-data -m 2770 /var/www/html/data
sudo install -d -o iot-alarm-monitor -g www-data -m 0750 /var/www/html/data/recordings
```

`www-data` erhaelt weder `dialout` noch `sudo`; Serial-Port und Recorder
gehoeren nur dem Dienstbenutzer.

### PHP-FPM und einmaliger Bootstrap

```bash
sudo install -d -o www-data -g www-data -m 0700 /var/lib/iot-alarm
sudoedit /etc/php/8.4/fpm/pool.d/www.conf
```

Die folgenden Zeilen **innerhalb des vorhandenen `[www]`-Pools** eintragen:

```ini
env[IOT_ALARM_BOOTSTRAP_FILE] = /var/lib/iot-alarm/bootstrap.txt
env[IOT_ALARM_DATA_DIR] = /var/www/html/data
env[ALARM_IPC_SOCKET] = /run/iot-alarm-monitor/control.sock
```

```bash
sudo php-fpm8.4 -t
sudo systemctl restart php8.4-fpm
```

Beim ersten HTTPS-Aufruf erzeugt PHP Admin-Passwort, Alarm-PIN,
geraetespezifische API-/Delivery-Secrets und das gemeinsame UDP-Secret. Die
Bootstrap-Datei bleibt `0600`: lokal ablesen, Passwort/PIN ersetzen, ESPs
provisionieren und erst dann sicher loeschen. Sie darf nie per HTTP erreichbar
sein.

### TLS und nginx

```bash
sudo openssl req -x509 -nodes -days 365 -newkey rsa:3072 -keyout /etc/ssl/private/iot-dashboard.key -out /etc/ssl/certs/iot-dashboard.crt
sudo htpasswd -c /etc/nginx/.htpasswd-cam camera
```

In `web/deploy/nginx/iot-dashboard.conf` `<PI_IP_OR_HOSTNAME>`, `<PI_LAN_IP>`,
`<API_PORT>`, `<TRUSTED_LAN_CIDR>` und `<CAM_PORT>` ersetzen. Bei anderem
PHP-FPM-Socket auch `fastcgi_pass` anpassen.

```bash
sudo install -m 0644 web/deploy/nginx/iot-dashboard.conf /etc/nginx/sites-available/iot-dashboard
sudo ln -s /etc/nginx/sites-available/iot-dashboard /etc/nginx/sites-enabled/iot-dashboard
sudo rm -f /etc/nginx/sites-enabled/default
sudo nginx -t
sudo systemctl reload nginx
```

Fuer den regulaeren Betrieb ein vertrauenswuerdiges Zertifikat verwenden.

### Alarm-Monitor und Fail2ban

```bash
sudo install -m 0644 web/alarm_monitor.service /etc/systemd/system/iot-alarm-monitor.service
sudo install -m 0640 -o root -g root web/deploy/systemd/iot-alarm-monitor.env.example /etc/default/iot-alarm-monitor
sudo systemctl daemon-reload
sudo systemctl enable --now iot-alarm-monitor.service
```

In `/etc/default/iot-alarm-monitor` einen `/dev/serial/by-id/...`-Pfad nutzen.
Abweichende Daten-/Socketpfade muessen in PHP-FPM und Dienst uebereinstimmen;
bei anderem Datenpfad auch `ReadWritePaths=` per Unit-Override anpassen. Der
Dienst besitzt Serial, ffmpeg, Loeschpfade und Runtime-Log exklusiv; die Kamera
erwartet einen lokal gebundenen MJPEG-Stream.

Im aktiven `[www]`-Pool ausserdem setzen:

```ini
php_admin_flag[log_errors] = on
php_admin_value[error_log] = /var/log/fpm-php.www.log
```

```bash
sudo touch /var/log/fpm-php.www.log
sudo chown www-data:adm /var/log/fpm-php.www.log
sudo chmod 0640 /var/log/fpm-php.www.log
sudo php-fpm8.4 -t
sudo systemctl restart php8.4-fpm
sudo install -m 0644 web/deploy/fail2ban/filter.d/iot-login.conf /etc/fail2ban/filter.d/iot-login.conf
sudo install -m 0644 web/deploy/fail2ban/jail.d/iot-login.conf /etc/fail2ban/jail.d/iot-login.conf
sudo fail2ban-client -t
sudo systemctl restart fail2ban
sudo fail2ban-client status iot-login
```

Nur Loopback bleibt in `ignoreip`; keine Admin-/IoT-Netze pauschal ausnehmen.

## Danach

[Hardware](HARDWARE.md#deutsch) pruefen, [Security](../SECURITY.md#deutsch)
umsetzen und [Tests](TESTING.md#deutsch) ausfuehren.

<div align="center">



</div>

---

# Build and Installation

This guide covers the three active firmware targets and the canonical
Raspberry Pi deployment. Historical sketches are not build inputs.

## Verified Versions

Arduino CLI `1.5.1`; ESP8266 core `3.1.2`; AVR Boards `1.8.8`;
ArduinoJson `7.4.3`; WiFiManager `2.0.17`; TelnetStream `1.3.0`;
NetApiHelpers `1.0.3`; MFRC522 `1.4.12`; PHP `8.4.25`; Node.js `24.14`.

Newer versions are outside this evidence. Known ArduinoJson/ESP8266
deprecation warnings are not build failures.

## Arduino Toolchain

```bash
arduino-cli config init
arduino-cli core update-index
arduino-cli core install arduino:avr@1.8.8
arduino-cli core install esp8266:esp8266@3.1.2 --additional-urls https://arduino.esp8266.com/stable/package_esp8266com_index.json
arduino-cli lib install "ArduinoJson@7.4.3"
arduino-cli lib install "WiFiManager@2.0.17"
arduino-cli lib install "TelnetStream@1.3.0"
arduino-cli lib install "NetApiHelpers@1.0.3"
arduino-cli lib install "MFRC522@1.4.12"
```

## Build the Firmware

```bash
arduino-cli compile --fqbn arduino:avr:uno firmware/elegoo_uno_r3/sketchR3/alarm_system
arduino-cli compile --fqbn esp8266:esp8266:nodemcuv2 firmware/esp8266/sender
arduino-cli compile --fqbn esp8266:esp8266:nodemcuv2 firmware/esp8266/receiver
```

Append `--port <PORT> --upload` to upload.

## Local RFID UIDs

The Uno default builds fail-closed and accepts no card. For real hardware, copy
`uid_whitelist.local.h.example` to `uid_whitelist.local.h` and insert locally read
UID bytes and length. Never commit the ignored `*.local.h`. The unchanged template
deliberately fails to compile; test disarmed with your own card.

## ESP First-Time Setup

Without a primary SSID, `Alarm-Sender-Konfig` or `Alarm-Empfaenger-Konfig` starts;
random WPA2 setup-AP/Telnet passwords are printed only over serial. On an isolated
network set: the same UDP HMAC secret (`>=32` characters) on both ESPs; a separate
32-character API token and delivery HMAC (`>=32`) per device; API IP, primary/
backup WiFi, and debug-Telnet password.

Never swap sender and receiver values. Upgrade both to `V15`; signed UDP ACKs
and `ALARMv2` are not fully compatible with older firmware. During migration,
a suitable legacy HMAC remains only as UDP secret; global legacy tokens and
delivery keys are removed. Intact WiFi values may stay; missing configuration
or delivery HMAC requires provisioning again and creates durable UDP/API high-water marks.

## Raspberry Pi Deployment

Browser access uses HTTPS through `nginx`; only `api.php` also has an HTTP
listener restricted to the IoT subnet for the ESPs.

### Packages and files

```bash
sudo apt update
sudo apt install nginx php8.4-fpm python3-serial ffmpeg rsync fail2ban apache2-utils
sudo install -d -o root -g root -m 0755 /var/www/html
sudo rsync -a --delete --chown=root:root --exclude data/ --exclude deploy/ --exclude README.md web/ /var/www/html/
sudo useradd --system --no-create-home --home-dir /nonexistent --shell /usr/sbin/nologin --gid www-data iot-alarm-monitor
sudo install -d -o iot-alarm-monitor -g www-data -m 2770 /var/www/html/data
sudo install -d -o iot-alarm-monitor -g www-data -m 0750 /var/www/html/data/recordings
```

Grant `www-data` neither `dialout` nor `sudo`; only the service account owns
serial and recorder resources.

### PHP-FPM and one-time bootstrap

```bash
sudo install -d -o www-data -g www-data -m 0700 /var/lib/iot-alarm
sudoedit /etc/php/8.4/fpm/pool.d/www.conf
```

Add these lines **inside the existing `[www]` pool**:

```ini
env[IOT_ALARM_BOOTSTRAP_FILE] = /var/lib/iot-alarm/bootstrap.txt
env[IOT_ALARM_DATA_DIR] = /var/www/html/data
env[ALARM_IPC_SOCKET] = /run/iot-alarm-monitor/control.sock
```

```bash
sudo php-fpm8.4 -t
sudo systemctl restart php8.4-fpm
```

The first HTTPS request creates an admin password, alarm PIN, device-specific
API/delivery secrets, and the shared UDP secret. The bootstrap file stays
`0600`: read it locally, replace password/PIN, provision the ESPs, then delete
it securely. It must never be served over HTTP.

### TLS and nginx

```bash
sudo openssl req -x509 -nodes -days 365 -newkey rsa:3072 -keyout /etc/ssl/private/iot-dashboard.key -out /etc/ssl/certs/iot-dashboard.crt
sudo htpasswd -c /etc/nginx/.htpasswd-cam camera
```

Replace `<PI_IP_OR_HOSTNAME>`, `<PI_LAN_IP>`, `<API_PORT>`,
`<TRUSTED_LAN_CIDR>`, and `<CAM_PORT>` in
`web/deploy/nginx/iot-dashboard.conf`. Adapt `fastcgi_pass` for another FPM
socket.

```bash
sudo install -m 0644 web/deploy/nginx/iot-dashboard.conf /etc/nginx/sites-available/iot-dashboard
sudo ln -s /etc/nginx/sites-available/iot-dashboard /etc/nginx/sites-enabled/iot-dashboard
sudo rm -f /etc/nginx/sites-enabled/default
sudo nginx -t
sudo systemctl reload nginx
```

Use a trusted certificate for regular operation.

### Alarm monitor and Fail2ban

```bash
sudo install -m 0644 web/alarm_monitor.service /etc/systemd/system/iot-alarm-monitor.service
sudo install -m 0640 -o root -g root web/deploy/systemd/iot-alarm-monitor.env.example /etc/default/iot-alarm-monitor
sudo systemctl daemon-reload
sudo systemctl enable --now iot-alarm-monitor.service
```

Use a `/dev/serial/by-id/...` path in `/etc/default/iot-alarm-monitor`.
Custom data/socket paths must match in PHP-FPM and the service; for another
data path, also override `ReadWritePaths=`. The daemon exclusively owns serial,
ffmpeg, deletion paths, and its runtime log; the camera expects a locally bound
MJPEG stream.

Also add to the active `[www]` pool:

```ini
php_admin_flag[log_errors] = on
php_admin_value[error_log] = /var/log/fpm-php.www.log
```

```bash
sudo touch /var/log/fpm-php.www.log
sudo chown www-data:adm /var/log/fpm-php.www.log
sudo chmod 0640 /var/log/fpm-php.www.log
sudo php-fpm8.4 -t
sudo systemctl restart php8.4-fpm
sudo install -m 0644 web/deploy/fail2ban/filter.d/iot-login.conf /etc/fail2ban/filter.d/iot-login.conf
sudo install -m 0644 web/deploy/fail2ban/jail.d/iot-login.conf /etc/fail2ban/jail.d/iot-login.conf
sudo fail2ban-client -t
sudo systemctl restart fail2ban
sudo fail2ban-client status iot-login
```

Keep only loopback in `ignoreip`; never blanket-exempt admin/IoT networks.

## Next Steps

Check [Hardware](HARDWARE.md#english), apply
[Security](../SECURITY.md#english), and run [Tests](TESTING.md#english).

<div align="center">



</div>

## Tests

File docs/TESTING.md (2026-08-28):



<div align="center">




</div>

---

# Tests

Automatisierte Nachweise und reale Hardwaretests sind getrennt. Ein gruener Lauf ist kein Safety-
oder Security-Zertifikat.

## Automatisierte Pruefungen

`Verify` nutzt Ubuntu 24.04, Python 3.13, Node.js 24 und die gepinnte
[Arduino-Toolchain](BUILD.md#de-versionen). Aus dem Repository-Root:

```bash
bash tests/ci/compile_firmware.sh
bash tests/ci/run_host_firmware_tests.sh
python3 -m unittest discover -v -s tests/runtime_deploy -p 'test_*.py'
bash tests/ci/check_php.sh
find . -path ./.git -prune -o -type f -name '*.js' -print0 \
  | xargs -0 -n1 node --check
python3 tests/ci/check_markdown_links.py
yamllint --strict -c tests/ci/yamllint-actions.yml .github/workflows
git diff --check
```

Der Workflow `Secret Scan` prueft die vollstaendige Historie mit Gitleaks und `.gitleaks.toml`.

## Bestaetigter Stand

| Bereich | Ergebnis und Abdeckung |
|---|---|
| Firmware | `6/6`: Sender Release `39 %` Flash/`43 %` RAM, Debug `39 %`/`44 %`; Empfaenger Release/Debug `39 %`/`43 %`; Uno Default/Beispiel `23 %`/`12 %`; ESP-IRAM `93 %` |
| Host-C++ | `2/2`: Uno-FSM fail-secure; Empfaenger verwirft Sequenz `99` nach `100` |
| Runtime Ubuntu | `17/17`: Serial, STATUS, IPC/TTL/Replay, Arm/Disarm, Recorder, aktiver Loeschschutz, Logrotation |
| Runtime Windows | `16` bestanden, `1` `AF_UNIX`-Test uebersprungen |
| PHP `8.4` | `21` Dateien lintfrei; `6` Suiten: Audit (`40`), Bootstrap, Brute Force (`80`), HTTP-E2E, Protokoll, paralleles Status-RMW (`40`) |
| JavaScript | `2/2` Dateien mit `node --check` |
| Markdown | `9/9` Dokumente: Pfade, Grossschreibung, DE/EN-Anker und GIF-Embeds |
| Fail2ban | IPv4, IPv6 und Tier 2 matchen; Injection nicht; kein installierter Jail-Livetest |

## Deployment pruefen

```bash
sudo nginx -t
sudo systemctl daemon-reload
sudo systemctl restart iot-alarm-monitor.service
sudo systemctl status nginx php8.4-fpm iot-alarm-monitor.service
sudo systemctl show iot-alarm-monitor.service \
  -p User -p Group -p SupplementaryGroups
sudo stat -c '%U %G %a %n' /run/iot-alarm-monitor/control.sock
id www-data
sudo -l -U www-data
sudo fail2ban-client -t
sudo fail2ban-client status iot-login
```

Erwartet: Dienst `iot-alarm-monitor:www-data` mit `SupplementaryGroups=dialout`; Socket
`iot-alarm-monitor:www-data`, Modus `660`; fuer `www-data` weder `dialout` noch `sudo`. Im Journal
muessen Uno-`STATUS`-Handshake und periodische Antworten erscheinen.

## Manueller Hardwaretest

1. Leere UID-Whitelist: jede Karte wird abgelehnt.
2. Private Test-UID: lokal und per Dashboard scharf/unscharf; Erfolg nur mit bestaetigtem Snapshot.
3. Jeden Reed-Kreis einzeln oeffnen; beide muessen scharf Alarm ausloesen.
4. Uno in `UNSCHARF`, `SCHARF`, `ALARM` neu starten; EEPROM wiederherstellen, korrupte nichtleere
   Testdaten muessen fail-secure Alarm ausloesen.
5. USB-Serial trennen/verbinden; aktive Alarmaufnahme bleibt bis zum validierten Reconnect-Snapshot.
6. Sender/Empfaenger: Alarm, signiertes ACK, Duplikat, Neustart und offene Dashboard-Zustellung.
7. Auf Test-Flash provisionierten LittleFS-Security-Record entfernen/beschaedigen: Sender sperrt
   Remote-Pfade, Empfaenger aktiviert zusaetzlich physische Alarmausgaenge.
8. Aufnahmegrenzen, voller Datentraeger, Kameraausfall und Loeschschutz der aktiven Datei pruefen.

## Nachweisgrenze

Serial und ffmpeg sind simuliert. Nicht abgedeckt: Langzeitbetrieb, Versorgungsmessung,
Funkstoerung, SD-Karten-Stromausfall und unabhaengiger Pentest. Fotos und fuenf Demo-GIFs zeigen den
Prototyp, sind aber kein formaler Nachweis.

<div align="center">



</div>

---

# Tests

Automated evidence and real hardware tests remain separate. A green run is not a safety or security
certificate.

## Automated Checks

`Verify` uses Ubuntu 24.04, Python 3.13, Node.js 24, and the pinned
[Arduino toolchain](BUILD.md#en-versions). From the repository root:

```bash
bash tests/ci/compile_firmware.sh
bash tests/ci/run_host_firmware_tests.sh
python3 -m unittest discover -v -s tests/runtime_deploy -p 'test_*.py'
bash tests/ci/check_php.sh
find . -path ./.git -prune -o -type f -name '*.js' -print0 \
  | xargs -0 -n1 node --check
python3 tests/ci/check_markdown_links.py
yamllint --strict -c tests/ci/yamllint-actions.yml .github/workflows
git diff --check
```

The `Secret Scan` workflow scans the complete history with Gitleaks and `.gitleaks.toml`.

## Confirmed Status

| Area | Result and coverage |
|---|---|
| Firmware | `6/6`: sender release `39%` flash/`43%` RAM, debug `39%`/`44%`; receiver release/debug `39%`/`43%`; Uno default/example `23%`/`12%`; ESP IRAM `93%` |
| Host C++ | `2/2`: Uno FSM fail-secure; receiver rejects sequence `99` after `100` |
| Runtime Ubuntu | `17/17`: serial, STATUS, IPC/TTL/replay, arm/disarm, recorder, active-file guard, log rotation |
| Runtime Windows | `16` passed, `1` `AF_UNIX` test skipped |
| PHP `8.4` | `21` files lint clean; `6` suites: audit (`40`), bootstrap, brute force (`80`), HTTP E2E, protocol, concurrent status RMW (`40`) |
| JavaScript | `2/2` files passed `node --check` |
| Markdown | `9/9` documents: paths, exact case, DE/EN anchors, and GIF embeds |
| Fail2ban | IPv4, IPv6, and tier 2 match; injection does not; no installed-jail live test |

## Verify the Deployment

```bash
sudo nginx -t
sudo systemctl daemon-reload
sudo systemctl restart iot-alarm-monitor.service
sudo systemctl status nginx php8.4-fpm iot-alarm-monitor.service
sudo systemctl show iot-alarm-monitor.service \
  -p User -p Group -p SupplementaryGroups
sudo stat -c '%U %G %a %n' /run/iot-alarm-monitor/control.sock
id www-data
sudo -l -U www-data
sudo fail2ban-client -t
sudo fail2ban-client status iot-login
```

Expected: service `iot-alarm-monitor:www-data` with `SupplementaryGroups=dialout`; socket
`iot-alarm-monitor:www-data`, mode `660`; neither `dialout` nor `sudo` for `www-data`. The journal must
show a Uno `STATUS` handshake and periodic responses.

## Manual Hardware Test

1. Empty UID whitelist: every card is rejected.
2. Private test UID: arm/disarm locally and through dashboard; success requires a confirmed snapshot.
3. Open each reed circuit separately; either must trigger an armed system.
4. Restart Uno in `UNSCHARF`, `SCHARF`, `ALARM`; restore EEPROM, while corrupt non-empty test state
   must fail secure into alarm.
5. Disconnect/reconnect USB serial; active alarm recording remains through validated reconnect.
6. Sender/receiver: alarm, signed ACK, duplicate, restart, and pending dashboard delivery.
7. On test flash remove/corrupt a provisioned LittleFS security record: sender disables remote paths;
   receiver also activates physical alarm outputs.
8. Test recording limits, full disk, camera failure, and active-file deletion protection.

## Evidence Boundary

Serial and ffmpeg are simulated. Not covered: endurance, supply measurement, radio interference,
SD-card power loss, or independent penetration testing. Photos and five demo GIFs show the prototype
but are not formal evidence.

<div align="center">



</div>

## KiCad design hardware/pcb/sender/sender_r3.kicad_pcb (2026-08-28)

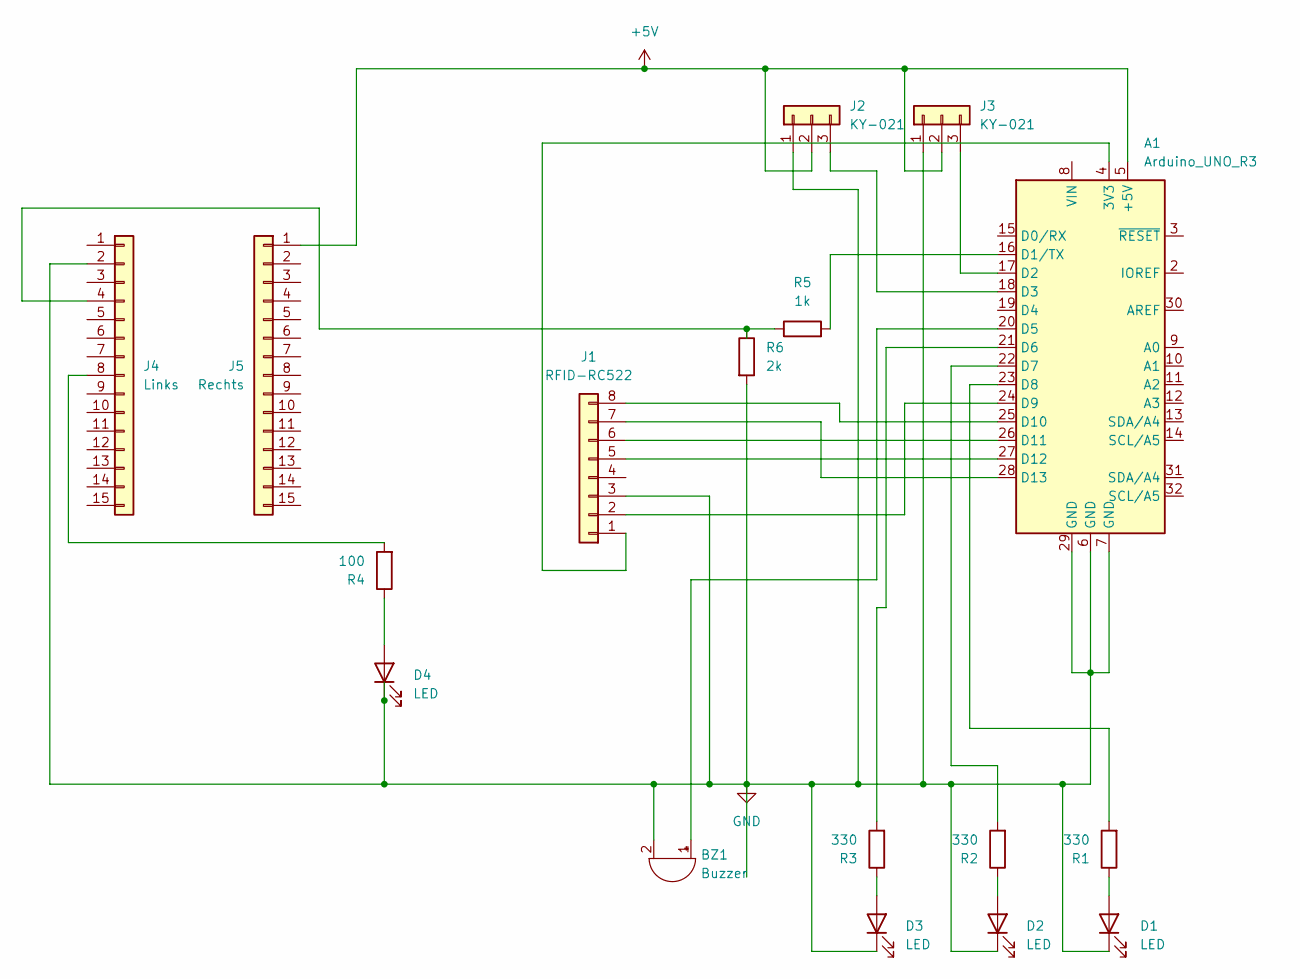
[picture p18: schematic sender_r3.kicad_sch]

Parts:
A1: Arduino_UNO_R3
BZ1: Buzzer; Buzzer_D14mm_H7mm_P10mm
D1, D2, D3, D4: LED; LED_D5.0mm
J1: RFID-RC522; PinHeader_1x08_P2.54mm_Vertical
J2, J3: KY-021; PinHeader_1x03_P2.54mm_Vertical
J4: Links; PinHeader_1x15_P2.54mm_Vertical
J5: Rechts; PinHeader_1x15_P2.54mm_Vertical
R1, R2, R3: 330; R_Axial_DIN0207_L6.3mm_D2.5mm_P7.62mm_Horizontal
R4: 100; R_Axial_DIN0207_L6.3mm_D2.5mm_P7.62mm_Horizontal
R5: 1k; R_Axial_DIN0207_L6.3mm_D2.5mm_P7.62mm_Horizontal
R6: 2k; R_Axial_DIN0207_L6.3mm_D2.5mm_P7.62mm_Horizontal

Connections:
+5V: A1.5 (+5V), J2.2, J3.2, J5.1
GND: A1.6 (GND), A1.7 (GND), A1.29 (GND), BZ1.2 (-), D1.1 (K), D2.1 (K), D3.1 (K), D4.1 (K), J1.3, J2.1, J3.1, J4.2, R6.2
unnamed: A1.4 (3V3), J1.1
unnamed: A1.16 (D1/TX), R5.2
unnamed: A1.17 (D2), J3.3
unnamed: A1.18 (D3), J2.3
unnamed: A1.20 (D5), BZ1.1 (+)
unnamed: A1.21 (D6), R3.2
unnamed: A1.22 (D7), R2.2
unnamed: A1.23 (D8), R1.2
unnamed: A1.24 (D9), J1.2
unnamed: A1.25 (D10), J1.8
unnamed: A1.26 (D11), J1.6
unnamed: A1.27 (D12), J1.5
unnamed: A1.28 (D13), J1.7
unnamed: D1.2 (A), R1.1
unnamed: D2.2 (A), R2.1
unnamed: D3.2 (A), R3.1
unnamed: D4.2 (A), R4.1
unnamed: J4.4, R5.1, R6.1
unnamed: J4.8, R4.2

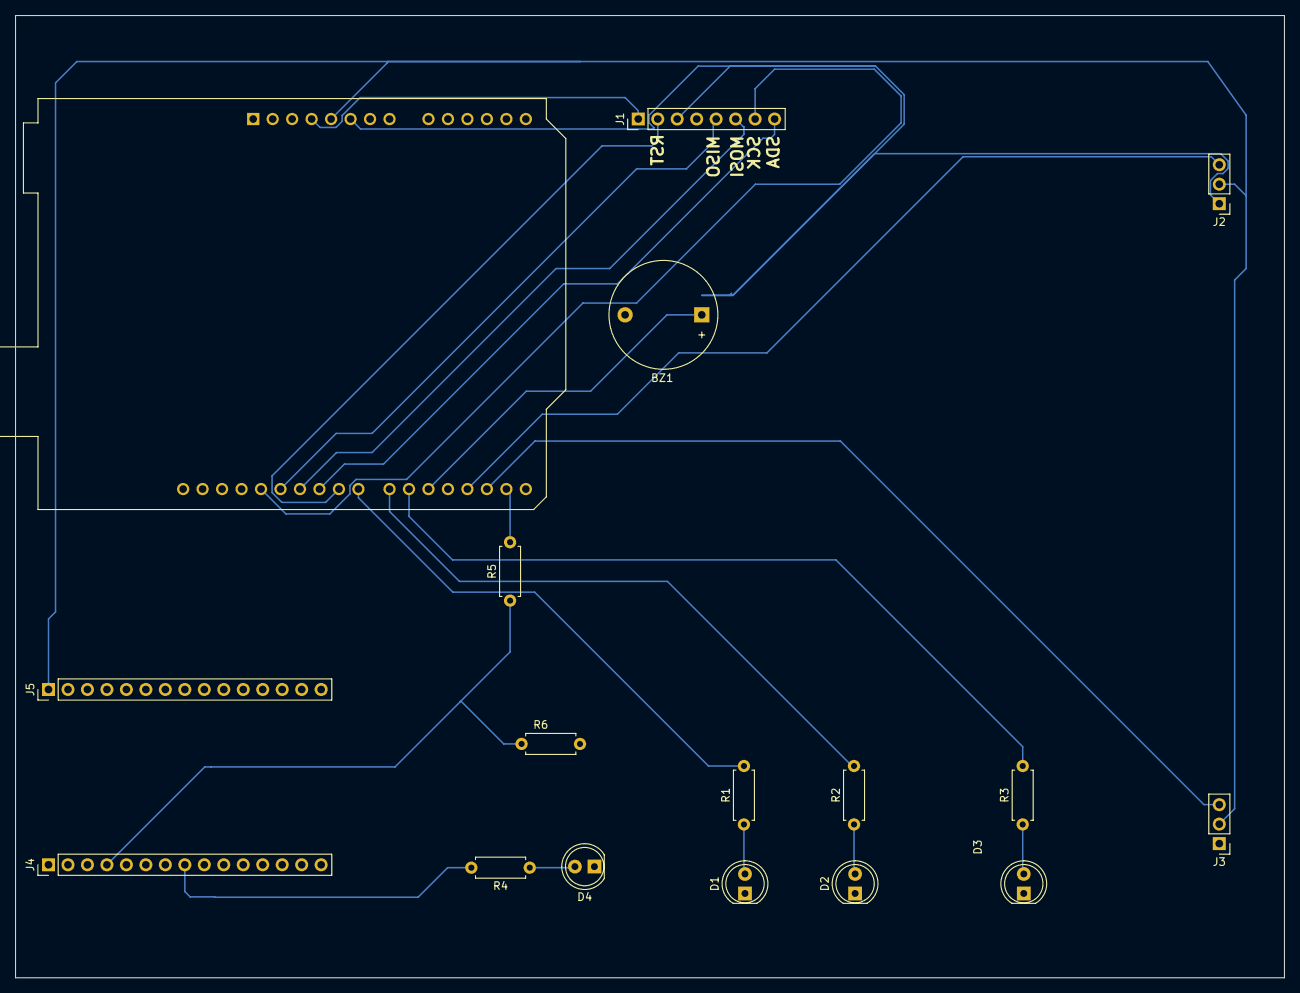
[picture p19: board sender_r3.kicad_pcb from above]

Board: 2 copper layers, 165.5 x 125.5 mm, 17 parts (0 on the bottom side), 21 nets.

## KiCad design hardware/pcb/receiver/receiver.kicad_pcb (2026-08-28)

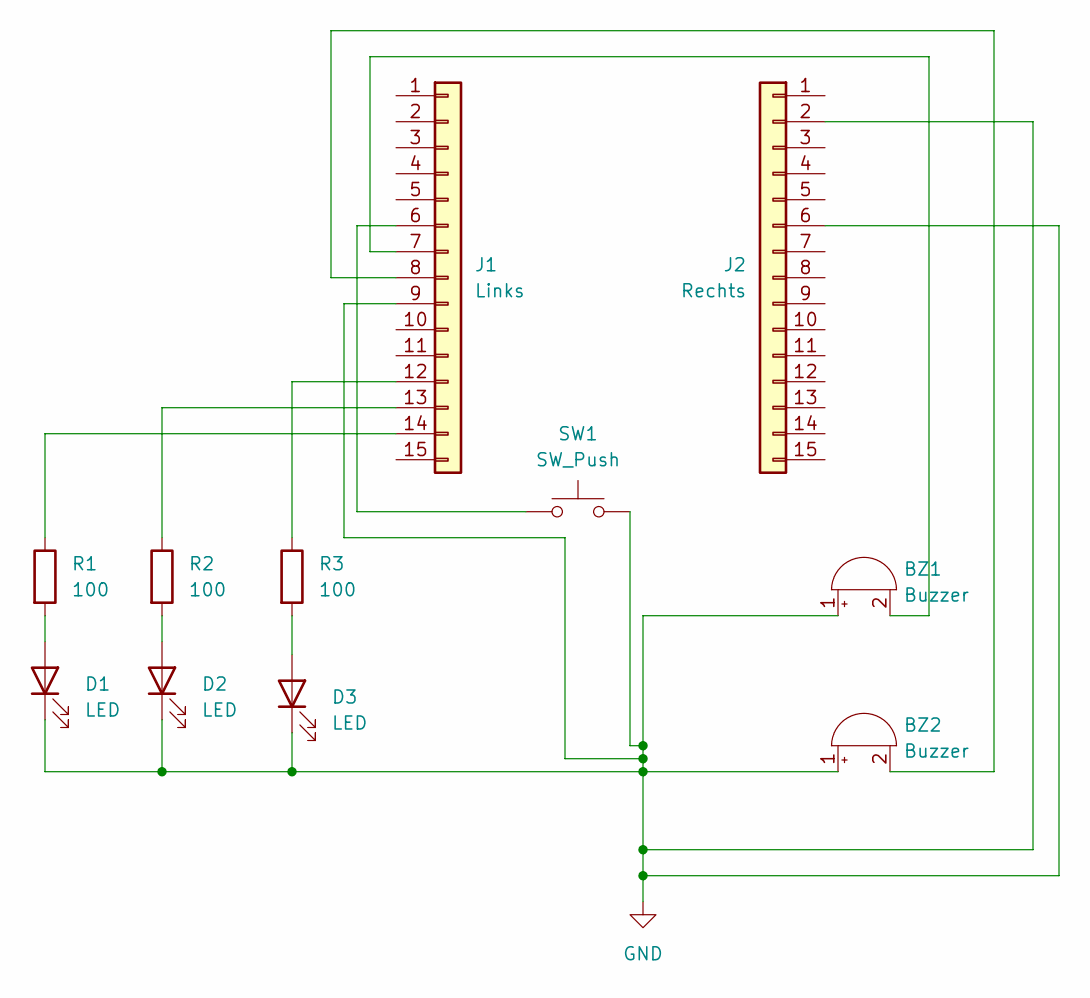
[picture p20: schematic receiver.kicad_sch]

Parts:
BZ1, BZ2: Buzzer; Buzzer_D14mm_H7mm_P10mm
D1, D2, D3: LED; LED_D5.0mm
J1: Links; PinSocket_1x15_P2.54mm_Vertical
J2: Rechts; PinSocket_1x15_P2.54mm_Vertical
R1, R2, R3: 100; R_Axial_DIN0207_L6.3mm_D2.5mm_P7.62mm_Horizontal
SW1: SW_Push; SW_PUSH_1P1T_6x3.5mm_H5.0_APEM_MJTP1250

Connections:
GND: BZ1.1 (+), BZ2.1 (+), D1.1 (K), D2.1 (K), D3.1 (K), J1.9, J2.2, J2.6, SW1.2
unnamed: BZ1.2 (-), J1.7
unnamed: BZ2.2 (-), J1.8
unnamed: D1.2 (A), R1.2
unnamed: D2.2 (A), R2.2
unnamed: D3.2 (A), R3.2
unnamed: J1.6, SW1.1
unnamed: J1.12, R3.1
unnamed: J1.13, R2.1
unnamed: J1.14, R1.1

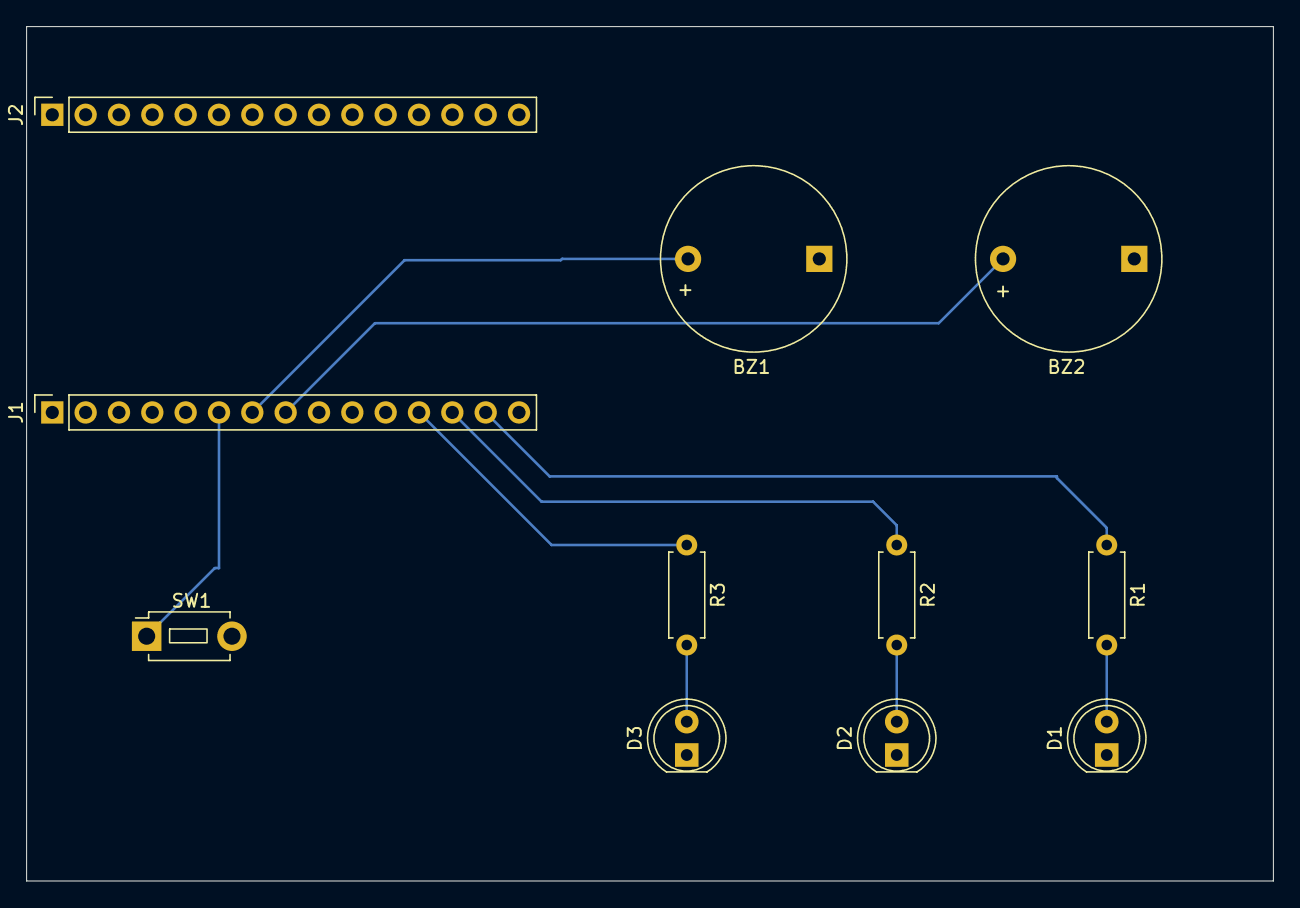
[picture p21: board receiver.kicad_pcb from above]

Board: 2 copper layers, 95.0 x 65.1 mm, 11 parts (0 on the bottom side), 10 nets.

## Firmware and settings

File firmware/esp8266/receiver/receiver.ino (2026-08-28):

/*
 * PROJEKT: ESP8266 UDP Alarm-System (Empfaenger)
 * -----------------------------------------------
 * Architektur: Hardware Abstraction Layer (HAL) + Finite State Machine (FSM)
 *
 * Schichten-Modell:
 *   [FSM]      - Zustandslogik: INIT -> WLAN_VERBINDEN -> BEREIT <-> ALARM -> WERKSRESET
 *   [Service]  - Sicherheit (HMAC, Replay-Window), Protokoll, Heartbeat, UDP-Verarbeitung
 *   [HAL]      - Hardware-Abstraktion: GPIO, WiFi, UDP, Flash, Timer, Telnet, mDNS
 *
 * Security: HMAC-SHA256, strikt monotoner Replay-Schutz (LittleFS-persistent),
 *           Constant-Time Signatur-Vergleich, isdigit-Validierung,
 *           Binary String Obfuscation (Flash), DoS Rate-Limiting
 *
 * Resilienz: Flash Wear-Leveling (LittleFS), Emergency QoS (Log-Filterung im Alarm),
 *            Remote-Override via Heartbeat-Kanal, Zero-Allocation UDP-Parsing
 *
 * Priority-Mode: Im ALARM-Zustand werden Heartbeat (bis auf Remote Control) und WLAN-Scan pausiert.
 *                Nur Hardware-Steuerung und UDP-Empfang laufen (Stop-the-World).
 *
 * Hardware:   NodeMCU V2 (ESP8266)
 * Autor:      Philip Keminer
 * Version:    V15.0 (signierte ACKs + persistente API-Replay-Abwehr)
 * Datum:      2026-03-04
 */

// ============================================================================
// BIBLIOTHEKEN
// ============================================================================

#include <FS.h>                      // Dateisystem-Grundfunktionen
#include <LittleFS.h>                // Flash-Dateisystem fuer ESP8266
#include <ArduinoJson.h>             // JSON-Parser fuer Konfiguration
#include "replay_schutz.h"           // Strikte Reihenfolge fuer Alarmbefehle
#include <ESP8266WiFi.h>             // WLAN-Funktionen
#include <WiFiManager.h>             // Captive Portal fuer WLAN-Konfiguration
#include <WiFiUdp.h>                 // UDP-Kommunikation
#include <ESP8266mDNS.h>             // mDNS-Responder (*.local)
#include <ESP8266HTTPClient.h>       // HTTP-Client fuer API-Calls
#include <WiFiClient.h>              // TCP-Client
#include <WiFiClientSecure.h>        // Fuer BearSSL HMAC-Bibliothek
#ifndef ALARM_ENABLE_TELNET
#define ALARM_ENABLE_TELNET 0        // Nur explizite Debug-Builds aktivieren
#endif
#if ALARM_ENABLE_TELNET
#include <TelnetStream.h>            // Debug-Konsole ueber Telnet
#endif
#include <Ticker.h>                  // Timer-Interrupts
#include <bearssl/bearssl.h>         // Kryptografie-Bibliothek
#include <libb64/cdecode.h>          // Base64-Decoding fuer verschluesselte Remote-Config
extern "C" {
#include <user_interface.h>          // Hardware-Zufallsquelle os_random()
}

// ============================================================================
// KONSTANTEN
// ============================================================================

const char* DEVICE_NAME = "alarm-receiver";  // Geraete-Identifikation

// --- Timing ---
const unsigned long ALARM_TOGGLE_INTERVALL = 200;          // LED/Summer-Wechsel alle 200ms (5 Hz)
const unsigned long WLAN_WIEDERHOLUNGS_INTERVALL = 20000;  // WLAN-Reconnect alle 20s
const unsigned long WLAN_SCAN_INTERVALL = 30000;           // Netzwerk-Scan alle 30s
const uint8_t STABILITAETS_SCHWELLWERT = 3;                // Hauptnetz muss 3x stabil sein
const int8_t RSSI_SCHWELLWERT = -75;                       // Mindest-Signalstaerke in dBm
const unsigned long TASTER_LANG_DRUCK = 1000;              // Kurzdruck-Schwelle: <1s = Toggle
const unsigned long TASTER_RESET_DRUCK = 10000;            // Langdruck: >10s = Factory Reset
const unsigned long BLINK_INTERVALL = 500;                 // WLAN-LED Blink-Intervall
const unsigned long HEARTBEAT_INTERVALL = 2000;            // Telemetrie alle 2s
const int WATCHDOG_TIMEOUT_SEK = 30;                       // Loop haengt nach 30s
const unsigned long TELNET_TIMEOUT = 300000;               // Session-Timeout: 5 Minuten

// --- Sicherheit ---
const uint8_t UDP_MAX_PAKETE_PRO_MINUTE = 60;             // DoS Rate-Limit
const uint8_t MAX_TELNET_VERSUCHE = 3;                    // Brute-Force-Schutz
const uint8_t REPLAY_FENSTER_GROESSE = 25;                // Persistenzformat-Kompatibilitaet

// --- Pins ---
#define PIN_LED_ROT  D1   // Alarm-LED 1 (wechselt mit Gelb)
#define PIN_LED_GELB D2   // Alarm-LED 2 (wechselt mit Rot)
#define PIN_LED_WLAN D3   // WLAN-Status-LED
#define PIN_SUMMER_1 D5   // Akustischer Alarm 1
#define PIN_SUMMER_2 D6   // Akustischer Alarm 2
#define PIN_TASTER   D7   // Toggle (<1s) / Reset (>10s)

// --- Obfuscated Payloads (Muss mit Sender uebereinstimmen!) ---
const char* CMD_ALARM_AN  = "NICE_TRY_WIRESHARK_USER";     // Verschleierter ALARM_ON Befehl
const char* CMD_ALARM_AUS = "ENCRYPTION_IS_YOUR_FRIEND";   // Verschleierter ALARM_OFF Befehl

// ============================================================================
// QUELLTEXT-VERSCHLEIERUNG (Kein Klartext in der Firmware)
// ============================================================================
// Diese Defaults hier sind nur Fallbacks fuer den allerersten Start.

// Decoder-Tabelle fuer Substitutions-Chiffre (liegt im Flash)
const char DECODER_TABLE[128] PROGMEM = {
    0, 1, 2, 3, 4, 5, 6, 7, 8, 9, 10, 11, 12, 13, 14, 15,
    16, 17, 18, 19, 20, 21, 22, 23, 24, 25, 26, 27, 28, 29, 30, 31,
    32, '1', 34, '3', '4', '5', '7', 39, '9', '0', '8', 43, 44, 45, 46, 47,
    48, 49, 50, 51, 52, 53, 54, 55, 56, 57, 58, 59, 60, 61, 62, 63,
    '2', 'V', 'F', 'Z', 'B', 'G', 'E', 'D', 'L', 'R', 'U', 'X', 'I', 'J', 'W', 'Q',
    'S', 'C', 'N', 'P', 'A', 'M', 'H', 'Y', 'T', 'O', 'K', 91, 92, 93, '6', 95,
    96, 'm', 'd', 'h', 'f', 'z', 'v', 'e', 'c', 'k', 'q', 'j', 'w', 'r', 'p', 'n',
    'i', 'o', 'u', 'g', 'x', 'b', 'y', 'l', 't', 's', 'a', 123, 124, 125, 126, 127
};

// Entschluesselt einen Text mit der Substitutions-Chiffre
void deobfuscate(char* text) {
    for (int i = 0; text[i] != '\0'; i++) {              // Durchlaufe String
        unsigned char idx = (unsigned char)text[i];      // Hole Zeichen
        if (idx < 128) {                                 // Nur ASCII
            char decoded = (char)pgm_read_byte(&DECODER_TABLE[idx]);  // Aus Flash lesen
            if (decoded != (char)idx) text[i] = decoded; // Ersetze wenn verschieden
        }
    }
}

// ============================================================================
// DATENSTRUKTUREN
// ============================================================================

// Zentrale System-Konfiguration
struct SystemKonfiguration {
    char udpToken[41] = "";             // HMAC-Secret (40 Zeichen + \0)
    char mdnsName[33] = "alarm-receiver"; // Eigener mDNS-Hostname
    char telnetPasswort[21] = "";  // Telnet-Login (verschleiert)
    char backupSsid[33] = "";           // Fallback-WLAN
    char backupPasswort[65] = "";       // Fallback-WLAN-Passwort
    char hauptWlanName[33] = "";        // Primaeres WLAN
    char hauptWlanPasswort[65] = "";    // Primaeres WLAN-Passwort
    char apPasswort[65] = "";  // Access-Point-Passwort (verschleiert)
    char apiServer[33] = "";            // API-Server IP-Adresse
    char apiToken[33] = "";             // Geraetespezifischer Bearer-Token
    char apiHmacToken[41] = "";         // Geraetespezifischer Delivery-HMAC
};

bool leseKonfigurationDatei(const char* pfad, SystemKonfiguration& ziel);

// FSM-Zustaende
enum SystemZustand {
    ZUSTAND_INIT,            // Einmalige Initialisierung
    ZUSTAND_WLAN_VERBINDEN,  // Captive Portal oder Direktverbindung
    ZUSTAND_BEREIT,          // Normalbetrieb: UDP empfangen, Heartbeat, Telnet
    ZUSTAND_ALARM,           // Priority Mode: Nur Hardware + UDP
    ZUSTAND_WERKSRESET       // Factory Reset
};

// ============================================================================
// HAL - HARDWARE ABSTRACTION LAYER
// ============================================================================

namespace HAL {

    // --- GPIO ---

    // Initialisiert alle GPIO-Pins
    void gpioInit() {
        pinMode(PIN_LED_WLAN, OUTPUT);      // WLAN-LED als Ausgang
        pinMode(PIN_LED_ROT, OUTPUT);       // Rote LED als Ausgang
        pinMode(PIN_LED_GELB, OUTPUT);      // Gelbe LED als Ausgang
        pinMode(PIN_SUMMER_1, OUTPUT);      // Summer 1 als Ausgang
        pinMode(PIN_SUMMER_2, OUTPUT);      // Summer 2 als Ausgang
        pinMode(PIN_TASTER, INPUT_PULLUP);  // Taster mit Pull-Up

        digitalWrite(PIN_LED_WLAN, LOW);    // WLAN-LED aus
        digitalWrite(PIN_LED_ROT, LOW);     // Rote LED aus
        digitalWrite(PIN_LED_GELB, LOW);    // Gelbe LED aus
        digitalWrite(PIN_SUMMER_1, LOW);    // Summer 1 aus
        digitalWrite(PIN_SUMMER_2, LOW);    // Summer 2 aus
    }

    // WLAN-LED setzen
    void wlanLed(bool an) {
        digitalWrite(PIN_LED_WLAN, an ? HIGH : LOW);  // LED setzen
    }

    // WLAN-LED umschalten (fuer Blink-Effekt)
    void wlanLedToggle() {
        digitalWrite(PIN_LED_WLAN, !digitalRead(PIN_LED_WLAN));  // Toggle
    }

    // Alarm-Hardware: Abwechselnd Rot/Gelb + Summer im 200ms-Takt
    void alarmHardwareSetzen(bool phase) {
        digitalWrite(PIN_LED_ROT,  phase ? HIGH : LOW);   // Rot an/aus
        digitalWrite(PIN_SUMMER_2, phase ? HIGH : LOW);   // Summer 2 an/aus
        digitalWrite(PIN_LED_GELB, phase ? LOW : HIGH);   // Gelb invertiert
        digitalWrite(PIN_SUMMER_1, phase ? HIGH : LOW);   // Summer 1 an/aus
    }

    // Schaltet alle Alarm-Hardware aus
    void alarmHardwareAus() {
        digitalWrite(PIN_SUMMER_1, LOW);    // Summer 1 aus
        digitalWrite(PIN_SUMMER_2, LOW);    // Summer 2 aus
        digitalWrite(PIN_LED_ROT, LOW);     // Rot aus
        digitalWrite(PIN_LED_GELB, LOW);    // Gelb aus
    }

    // Prueft ob Taster gedrueckt ist
    bool tasterGedrueckt() {
        return digitalRead(PIN_TASTER) == LOW;  // LOW = gedrueckt (Pull-Up)
    }

    // --- Watchdog ---

    Ticker watchdogTicker;           // Timer-Objekt
    volatile int watchdogZaehler = 0;  // Sekunden-Zaehler (ISR-sicher)
    volatile bool mussNeustarten = false;  // Neustart-Flag (ISR-sicher)

    // Watchdog-Interrupt (jede Sekunde)
    void ICACHE_RAM_ATTR watchdogISR() {
        watchdogZaehler++;                                    // Zaehler erhoehen
        if (watchdogZaehler >= WATCHDOG_TIMEOUT_SEK) mussNeustarten = true;  // Timeout
    }

    // Startet den Software-Watchdog
    void watchdogStarten() {
        watchdogTicker.attach(1.0, watchdogISR);  // ISR alle 1 Sekunde
    }

    // Stoppt den Software-Watchdog
    void watchdogStoppen() {
        watchdogTicker.detach();  // Timer deaktivieren
    }

    // Fuettert den Watchdog (setzt Zaehler zurueck)
    void watchdogFuettern() {
        watchdogZaehler = 0;  // Zaehler zuruecksetzen
    }

    // Prueft ob Watchdog ausgeloest wurde
    bool watchdogAusgeloest() {
        return mussNeustarten;  // Flag pruefen
    }

    // --- System ---

    // HAL-Initialisierung
    void init() {
        Serial.begin(9600);  // Serielle Konsole starten
        gpioInit();          // GPIO-Pins initialisieren
    }

    // System-Neustart
    void neustart() {
        delay(100);      // Kurz warten
        ESP.restart();   // Hardware-Neustart
    }

    unsigned long zeitMs() { return millis(); }          // Systemzeit in Millisekunden
    uint32_t freierHeap() { return ESP.getFreeHeap(); }  // Freier RAM
    String resetGrund() { return ESP.getResetReason(); } // Letzter Reset-Grund
    void cpuFreigeben() { yield(); }                     // CPU fuer WLAN freigeben

    // --- Flash (LittleFS) ---

    bool flashInit() { return LittleFS.begin(); }  // Dateisystem mounten
    void flashFormatieren() { LittleFS.format(); } // Dateisystem loeschen

    // --- WiFi ---

    bool wlanVerbunden() { return WiFi.status() == WL_CONNECTED; }  // Verbindungsstatus
    String wlanSsid() { return WiFi.SSID(); }       // Aktuelles WLAN
    int wlanRssi() { return WiFi.RSSI(); }          // Signalstaerke
    String wlanIp() { return WiFi.localIP().toString(); }  // IP-Adresse

    void wlanVerbinden(const char* ssid, const char* pw) { WiFi.begin(ssid, pw); }  // Verbinden
    void wlanTrennen() { WiFi.disconnect(true); }   // Trennen + Auto-Reconnect aus

    int wlanScanStarten() { WiFi.scanNetworks(true); return 0; }  // Async Scan
    int wlanScanErgebnis() { return WiFi.scanComplete(); }        // Scan-Status
    String wlanScanSsid(int i) { return WiFi.SSID(i); }           // SSID aus Scan
    int wlanScanRssi(int i) { return WiFi.RSSI(i); }              // RSSI aus Scan
    void wlanScanLoeschen() { WiFi.scanDelete(); }                // Scan-Ergebnisse freigeben

    // Loescht gespeicherte WLAN-Credentials (WiFiManager)
    void wlanCredentialsLoeschen() {
        WiFiManager wm;      // WiFiManager-Objekt
        wm.resetSettings();  // Gespeicherte SSIDs loeschen
    }

    // --- UDP ---

    WiFiUDP udpSocket;                   // UDP-Socket-Objekt
    const unsigned int LOKALER_PORT = 4210;   // Empfaenger-Port

    // Zwischenspeicher fuer Sender-Adresse (vor strtok sichern!)
    IPAddress letzterSenderIp;           // Absender-IP
    unsigned int letzterSenderPort = 0;  // Absender-Port
    IPAddress gebundeneSenderIp;          // Nach erster gueltiger HMAC gebundener Peer
    bool senderGebunden = false;

    // Startet UDP-Socket
    void udpStarten() {
        udpSocket.stop();
        udpSocket.begin(LOKALER_PORT);
        senderGebunden = false;           // Netzwechsel darf eine neue Peer-IP zulassen
    }

    // Prueft ob UDP-Paket empfangen wurde
    int udpPaketVerfuegbar() { return udpSocket.parsePacket(); }

    // Liest Paket und merkt sich Absender-Info fuer ACK
    int udpLesen(char* buf, size_t maxLen) {
        letzterSenderIp = udpSocket.remoteIP();    // Absender-IP merken
        letzterSenderPort = udpSocket.remotePort();  // Absender-Port merken
        return udpSocket.read(buf, maxLen);        // Paket lesen
    }

    // Sendet UDP-Antwort an letzten Absender
    void udpAntworten(const char* daten) {
        udpSocket.beginPacket(letzterSenderIp, letzterSenderPort);  // Paket starten
        udpSocket.print(daten);                    // Daten schreiben
        udpSocket.endPacket();                     // Paket absenden
    }

    bool udpAbsenderPlausibel() {
        if (letzterSenderPort != 4211) return false;
        return !senderGebunden || letzterSenderIp == gebundeneSenderIp;
    }

    void udpSenderBinden() {
        if (!senderGebunden) {
            gebundeneSenderIp = letzterSenderIp;
            senderGebunden = true;
        }
    }

    // Verwirft empfangenes Paket
    void udpFlush() { udpSocket.flush(); }

    // --- mDNS ---

    bool mdnsStarten(const char* hostname) { return MDNS.begin(hostname); }  // mDNS-Responder
    void mdnsUpdate() { MDNS.update(); }  // mDNS-Verarbeitung

    // --- Telnet ---

#if ALARM_ENABLE_TELNET
    void telnetStarten() { TelnetStream.begin(); }  // Telnet-Server starten
    bool telnetVerfuegbar() { return TelnetStream.available(); }  // Daten verfuegbar
    String telnetLesen() { String s = TelnetStream.readStringUntil('\n'); s.trim(); return s; }  // Zeile lesen
    void telnetSchreiben(const char* msg) { TelnetStream.println(msg); TelnetStream.flush(); }  // Zeile senden
    void telnetStoppen() { TelnetStream.stop(); }  // Telnet-Server stoppen
#else
    void telnetStarten() {}
    bool telnetVerfuegbar() { return false; }
    String telnetLesen() { return String(); }
    void telnetSchreiben(const char*) {}
    void telnetStoppen() {}
#endif

} // namespace HAL

// ============================================================================
// SECURITY - Sicherheitsfunktionen (plattformunabhaengig)
// ============================================================================
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
void loop() {
    HAL::watchdogFuettern();              // Watchdog fuettern
    if (HAL::watchdogAusgeloest()) {      // Watchdog ausgeloest
        Serial.println("WATCHDOG RESET!");  // Log
        HAL::neustart();                  // Neustart
    }
    fsmUpdate();                          // FSM aktualisieren
    HAL::cpuFreigeben();                  // CPU fuer WLAN freigeben
}

void generiereZufallsHex(char* ziel, size_t zielGroesse) {
    static const char HEX_ZEICHEN[] = "0123456789abcdef";
    if (zielGroesse < 2) return;
    for (size_t i = 0; i < zielGroesse - 1; i++) {
        if ((i & 7U) == 0) HAL::cpuFreigeben();
        ziel[i] = HEX_ZEICHEN[os_random() & 0x0F];
    }
    ziel[zielGroesse - 1] = '\0';
}

void sichereErststartSecrets() {
    bool geaendert = false;
    bool neuesApPasswort = false;
    bool neuesTelnetPasswort = false;
    if (strlen(config.apPasswort) < 12) {
        generiereZufallsHex(config.apPasswort, 17);
        geaendert = neuesApPasswort = true;
    }
    if (strlen(config.telnetPasswort) < 12) {
        generiereZufallsHex(config.telnetPasswort, 17);
        geaendert = neuesTelnetPasswort = true;
    }
    if (geaendert && !configStateCorrupt) speichereKonfiguration();
    if (neuesApPasswort) {
        Serial.print(F("SETUP AP PASSWORD (local serial only): "));
        Serial.println(config.apPasswort);
    }
    if (neuesTelnetPasswort) {
        Serial.print(F("TELNET PASSWORD (local serial only): "));
        Serial.println(config.telnetPasswort);
    }
}

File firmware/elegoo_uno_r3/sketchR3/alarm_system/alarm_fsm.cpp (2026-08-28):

// =============================================================================
// alarm_fsm.cpp - Zustandsautomat mit fail-secure EEPROM-Persistenz
// =============================================================================

#include "alarm_fsm.h"
#include "hal_io.h"
#include "hal_comm.h"
#include <EEPROM.h>

// Zwei alternierende Records verhindern, dass ein Stromausfall waehrend eines
// EEPROM-Schreibvorgangs den letzten gueltigen Zustand zerstoert. Das
// Commit-Byte wird immer zuletzt geschrieben; EEPROM.update vermeidet
// unnoetigen Verschleiss bei unveraenderten Bytes.
static const uint8_t EEPROM_SLOT_GROESSE = 7;
static const uint8_t EEPROM_SLOT_ANZAHL = 2;
static const uint8_t EEPROM_COMMIT_OFFSET = 6;
static const uint16_t EEPROM_MAGIC = 0xA17E;
static const uint8_t EEPROM_VERSION = 1;
static const uint8_t EEPROM_COMMIT = 0xA5;

static AlarmState zustand = STATE_UNSCHARF;
static uint8_t aktiverSlot = 0xFF;
static uint8_t aktiveSequenz = 0;

typedef enum {
  LADE_FRISCH,
  LADE_GUELTIG,
  LADE_KORRUPT
} LadeErgebnis;


static uint8_t crc8(const uint8_t* daten, uint8_t laenge) {
  uint8_t crc = 0xFF;
  for (uint8_t i = 0; i < laenge; i++) {
    crc ^= daten[i];
    for (uint8_t bit = 0; bit < 8; bit++) {
      crc = (crc & 0x80) ? static_cast<uint8_t>((crc << 1) ^ 0x31)
                         : static_cast<uint8_t>(crc << 1);
    }
  }
  return crc;
}


static int slotAdresse(uint8_t slot) {
  return static_cast<int>(slot) * EEPROM_SLOT_GROESSE;
}


static void leseSlot(uint8_t slot, uint8_t* record) {
  int adresse = slotAdresse(slot);
  for (uint8_t i = 0; i < EEPROM_SLOT_GROESSE; i++) {
    record[i] = EEPROM.read(adresse + i);
  }
}


static bool recordIstLeer(const uint8_t* record) {
  for (uint8_t i = 0; i < EEPROM_SLOT_GROESSE; i++) {
    if (record[i] != 0xFF) return false;
  }
  return true;
}


static bool zustandIstPersistierbar(uint8_t wert) {
  return wert == STATE_UNSCHARF || wert == STATE_SCHARF || wert == STATE_ALARM;
}


static bool recordIstGueltig(const uint8_t* record) {
  uint16_t magic = static_cast<uint16_t>(record[0]) |
                   (static_cast<uint16_t>(record[1]) << 8);
  return record[EEPROM_COMMIT_OFFSET] == EEPROM_COMMIT &&
         magic == EEPROM_MAGIC &&
         record[2] == EEPROM_VERSION &&
         zustandIstPersistierbar(record[4]) &&
         record[5] == crc8(record, 5);
}


static bool sequenzIstNeuer(uint8_t kandidat, uint8_t referenz) {
  return static_cast<int8_t>(kandidat - referenz) > 0;
}


static bool schreibeSlot(uint8_t slot, AlarmState neu, uint8_t sequenz) {
  uint8_t record[EEPROM_SLOT_GROESSE];
  record[0] = static_cast<uint8_t>(EEPROM_MAGIC & 0xFF);
  record[1] = static_cast<uint8_t>(EEPROM_MAGIC >> 8);
  record[2] = EEPROM_VERSION;
  record[3] = sequenz;
  record[4] = static_cast<uint8_t>(neu);
  record[5] = crc8(record, 5);
  record[6] = EEPROM_COMMIT;

  int adresse = slotAdresse(slot);
  EEPROM.update(adresse + EEPROM_COMMIT_OFFSET, 0x00);
  for (uint8_t i = 0; i < EEPROM_COMMIT_OFFSET; i++) {
    EEPROM.update(adresse + i, record[i]);
  }
  EEPROM.update(adresse + EEPROM_COMMIT_OFFSET, EEPROM_COMMIT);

  uint8_t pruefung[EEPROM_SLOT_GROESSE];
  leseSlot(slot, pruefung);
  return recordIstGueltig(pruefung) &&
         pruefung[3] == sequenz &&
         pruefung[4] == static_cast<uint8_t>(neu);
}


static LadeErgebnis ladeZustand(AlarmState* geladen) {
  uint8_t records[EEPROM_SLOT_ANZAHL][EEPROM_SLOT_GROESSE];
  bool leer[EEPROM_SLOT_ANZAHL];
  bool gueltig[EEPROM_SLOT_ANZAHL];

  for (uint8_t slot = 0; slot < EEPROM_SLOT_ANZAHL; slot++) {
    leseSlot(slot, records[slot]);
    leer[slot] = recordIstLeer(records[slot]);
    gueltig[slot] = recordIstGueltig(records[slot]);
  }

  if (leer[0] && leer[1]) {
    aktiverSlot = 0xFF;
    aktiveSequenz = 0;
    *geladen = STATE_UNSCHARF;
    return LADE_FRISCH;
  }

  // Nicht-leere, aber ungueltige Daten bedeuten unterbrochenen Schreibvorgang
  // oder Korruption. Auch wenn der zweite Slot noch gueltig ist, wird bewusst
  // ALARM gewaehlt statt moeglicherweise auf UNSCHARF zurueckzufallen.
  if ((!leer[0] && !gueltig[0]) || (!leer[1] && !gueltig[1])) {
    aktiverSlot = 0xFF;
    aktiveSequenz = 0;
    *geladen = STATE_ALARM;
    return LADE_KORRUPT;
  }

  uint8_t slot;
  if (gueltig[0] && gueltig[1]) {
    slot = sequenzIstNeuer(records[1][3], records[0][3]) ? 1 : 0;
  } else {
    slot = gueltig[0] ? 0 : 1;
  }

  aktiverSlot = slot;
  aktiveSequenz = records[slot][3];
  *geladen = static_cast<AlarmState>(records[slot][4]);
  return LADE_GUELTIG;
}


static bool persistiereZustand(AlarmState neu) {
  if (!zustandIstPersistierbar(static_cast<uint8_t>(neu))) return false;

  uint8_t zielSlot = (aktiverSlot == 0xFF) ? 0 : static_cast<uint8_t>(1 - aktiverSlot);
  uint8_t sequenz = (aktiverSlot == 0xFF) ? 1 : static_cast<uint8_t>(aktiveSequenz + 1);
  if (!schreibeSlot(zielSlot, neu, sequenz)) return false;

  aktiverSlot = zielSlot;
  aktiveSequenz = sequenz;
  return true;
}


static void repariereAlsAlarm() {
  if (schreibeSlot(0, STATE_ALARM, 1)) {
    aktiverSlot = 0;
    aktiveSequenz = 1;
    if (schreibeSlot(1, STATE_ALARM, 2)) {
      aktiverSlot = 1;
      aktiveSequenz = 2;
    }
  }
}


static void wendeEntryAktionenAn(AlarmState neu) {
  switch (neu) {
    case STATE_UNSCHARF:
      hal_buzzerAus();
      hal_comm_sendeEvent(EVT_ALARM_UNSCHARF);
      break;
    case STATE_SCHARF:
      hal_buzzerAus();
      hal_comm_sendeEvent(EVT_ALARM_SCHARF);
      break;
    case STATE_ALARM:
      hal_buzzerEin();
      hal_comm_sendeEvent(EVT_ALARM_ON);
      break;
    default:
      // Ein unbekannter Zustand darf nie still oder unscharf werden.
      hal_buzzerEin();
      hal_comm_sendeEvent(EVT_ALARM_ON);
      break;
  }
}


static void wechsleZu(AlarmState neu) {
  if (zustand == neu) return;

  AlarmState ziel = neu;
  if (!persistiereZustand(ziel)) {
    ziel = STATE_ALARM;
    persistiereZustand(ziel);
    hal_comm_sendeEvent(EVT_PERSISTENZ_FEHLER);
  }

  if (zustand == STATE_ALARM && ziel != STATE_ALARM) {
    hal_buzzerAus();
    hal_comm_sendeEvent(EVT_ALARM_OFF);
  }

  zustand = ziel;
  wendeEntryAktionenAn(zustand);
}


void fsm_init() {
  AlarmState geladen = STATE_UNSCHARF;
  LadeErgebnis ergebnis = ladeZustand(&geladen);
  zustand = geladen;

  if (ergebnis == LADE_KORRUPT) {
    repariereAlsAlarm();
    hal_comm_sendeEvent(EVT_PERSISTENZ_FEHLER);
  }

  // Boot stellt nicht nur die Variable, sondern auch Buzzer und das serielle
  // Ereignis wieder her. Dadurch startet die Kamera nach einem Reset im
  // laufenden Alarm erneut.
  wendeEntryAktionenAn(zustand);
}
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

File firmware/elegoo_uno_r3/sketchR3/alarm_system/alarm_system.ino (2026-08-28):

// =============================================================================
// alarm_system.ino - Alarmanlage mit RFID, Sensoren und Pico2W-Anbindung
// =============================================================================
//
// Aufbau:
//   hal_*.h/cpp   - Hardwareabstraktion (Pins, RFID, Kommunikation)
//   alarm_fsm     - Zustandsautomat (UNSCHARF/SCHARF/ALARM)
//   uid_check     - RFID-Whitelist
//
// =============================================================================

#include "hal_io.h"
#include "hal_rfid.h"
#include "hal_comm.h"
#include "hal_time.h"
#include "hal_system.h"
#include "alarm_fsm.h"
#include "sensor_logic.h"
#include "uid_check.h"
#include <avr/wdt.h> 

// =============================================================================
// Einstellungen
// =============================================================================

// Diese Werte koennen bei Bedarf als Build-Flags ueberschrieben werden, zum
// Beispiel mit -DALARM_HEARTBEAT_INTERVAL_MS=10000UL. Unsichere Kombinationen
// werden bereits beim Kompilieren abgelehnt.
#ifndef ALARM_SERIAL_BAUDRATE
#define ALARM_SERIAL_BAUDRATE 9600UL
#endif

#ifndef ALARM_HEARTBEAT_INTERVAL_MS
#define ALARM_HEARTBEAT_INTERVAL_MS 5000UL
#endif

#ifndef ALARM_HEARTBEAT_TIMEOUT_MS
#define ALARM_HEARTBEAT_TIMEOUT_MS 15000UL
#endif

#ifndef ALARM_RFID_COOLDOWN_MS
#define ALARM_RFID_COOLDOWN_MS 2000UL
#endif

#if ALARM_SERIAL_BAUDRATE < 1200UL || ALARM_SERIAL_BAUDRATE > 115200UL
#error "ALARM_SERIAL_BAUDRATE muss zwischen 1200 und 115200 liegen"
#endif

#if ALARM_HEARTBEAT_INTERVAL_MS < 1000UL
#error "ALARM_HEARTBEAT_INTERVAL_MS muss mindestens 1000 ms betragen"
#endif

#if ALARM_HEARTBEAT_TIMEOUT_MS <= ALARM_HEARTBEAT_INTERVAL_MS
#error "ALARM_HEARTBEAT_TIMEOUT_MS muss groesser als das Heartbeat-Intervall sein"
#endif

#if ALARM_RFID_COOLDOWN_MS < 250UL
#error "ALARM_RFID_COOLDOWN_MS muss mindestens 250 ms betragen"
#endif

static const uint32_t BAUDRATE = ALARM_SERIAL_BAUDRATE;
static const uint32_t HEARTBEAT_INTERVALL_MS = ALARM_HEARTBEAT_INTERVAL_MS;
static const uint32_t WATCHDOG_TIMEOUT_MS = ALARM_HEARTBEAT_TIMEOUT_MS;
static const uint32_t RFID_SPERRZEIT_MS = ALARM_RFID_COOLDOWN_MS;


// =============================================================================
// Variablen Heartbeat-Watchdog
// =============================================================================

static uint32_t letzterHeartbeat = 0;
static uint32_t letzteAntwort = 0;
static bool warteAufAntwort = false;
static bool verbindungAktiv = true;


// =============================================================================
// Variablen RFID
// =============================================================================

static uint32_t letzteRfidLesung = 0;
static bool karteWarDa = false;


// =============================================================================
// Heartbeat-Watchdog Funktionen
// =============================================================================

// Heartbeat senden (alle 5s)
void watchdog_sende() {
  uint32_t jetzt = hal_zeitMs();
  
  if (!warteAufAntwort && hal_zeitAbgelaufen(letzterHeartbeat, HEARTBEAT_INTERVALL_MS)) {
    hal_comm_sendeHeartbeat();
    letzterHeartbeat = jetzt;
    warteAufAntwort = true;
  }
}

// Timeout pruefen
void watchdog_pruefe() {
  if (warteAufAntwort && hal_zeitAbgelaufen(letzterHeartbeat, WATCHDOG_TIMEOUT_MS)) {
    if (verbindungAktiv) {
      verbindungAktiv = false;
      hal_comm_sendeEvent(EVT_VERBINDUNG_VERLOREN);
      hal_setStatusLED(true);
    }
    warteAufAntwort = false;
  }
}

// Antwort vom Pico2W erhalten
void watchdog_bestaetigt() {
  letzteAntwort = hal_zeitMs();
  warteAufAntwort = false;
  
  if (!verbindungAktiv) {
    verbindungAktiv = true;
    hal_comm_sendeEvent(EVT_VERBINDUNG_AKTIV);
    hal_setStatusLED(false);
  }
}


// =============================================================================
// RFID verarbeiten
// =============================================================================

AlarmInput rfid_verarbeite() {
  uint32_t jetzt = hal_zeitMs();
  
  // Sperrzeit aktiv -> ignorieren
  if (!hal_zeitAbgelaufen(letzteRfidLesung, RFID_SPERRZEIT_MS)) {
    return INPUT_KEINE;
  }
  
  // Karte lesen
  byte uid[HAL_RFID_MAX_UID_LEN];
  byte uidLen = 0;
  RfidStatus status = hal_rfid_leseKarte(uid, &uidLen);
  
  if (status == RFID_KEINE_KARTE) {
    karteWarDa = false;
    return INPUT_KEINE;
  }
  
  if (status == RFID_LESEFEHLER) {
    return INPUT_KEINE;
  }
  
  // Karte gelesen -> Sperrzeit starten
  letzteRfidLesung = jetzt;
  hal_rfid_beenden();
  
  // Entprellung: nur reagieren wenn Karte neu
  if (karteWarDa) {
    return INPUT_KEINE;
  }
  karteWarDa = true;
  
  // UID pruefen
  if (uid_istErlaubt(uid, uidLen)) {
    return INPUT_KARTE_ERLAUBT;
  }
  
  return INPUT_KEINE;
}


// =============================================================================
// Sensoren verarbeiten (fail-secure)
// =============================================================================

AlarmInput sensoren_verarbeite() {
  bool tuerOffen1 = hal_istTuerOffen1();
  bool tuerOffen2 = hal_istTuerOffen2();
  
  // Ein einzelner offener oder unterbrochener Reed-Kreis reicht aus. Die alte
  // AND-Verknuepfung konnte einen realen Einbruch bei nur einer Tuer oder
  // einem durchtrennten Sensorkabel unterdruecken.
  if (sensorAlarmErforderlich(fsm_istScharf(), fsm_istAusgeloest(),
                             tuerOffen1, tuerOffen2)) {
    return INPUT_SENSOR_OFFEN;
  }
  
  return INPUT_KEINE;
}


// =============================================================================
// Serielle Kommandos verarbeiten
// =============================================================================

AlarmInput kommando_verarbeite() {
  KommKommando cmd = hal_comm_leseKommando();
  
  switch (cmd) {
    case CMD_HEARTBEAT_ACK:
      watchdog_bestaetigt();
      return INPUT_KEINE;
      
    case CMD_ERZWINGE_ALARM:
      return INPUT_ERZWINGE_ALARM;
      
    case CMD_ALARM_STOP:
      return INPUT_ALARM_STOP;
      
    case CMD_SCHARF:
      return INPUT_CMD_SCHARF;
      
    case CMD_UNSCHARF:
      return INPUT_CMD_UNSCHARF;
      
    case CMD_STATUS:
      hal_comm_sendeStatus(
        fsm_istScharf(),
        fsm_istAusgeloest(),
        hal_istTuerOffen1(),
        hal_istTuerOffen2(),
        verbindungAktiv
      );
      return INPUT_KEINE;
      
    case CMD_REBOOT:
      hal_reboot();  // Kehrt nicht zurueck
      return INPUT_KEINE;
      
    default:
      return INPUT_KEINE;
  }
}


// =============================================================================
// LEDs aktualisieren
// =============================================================================
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
